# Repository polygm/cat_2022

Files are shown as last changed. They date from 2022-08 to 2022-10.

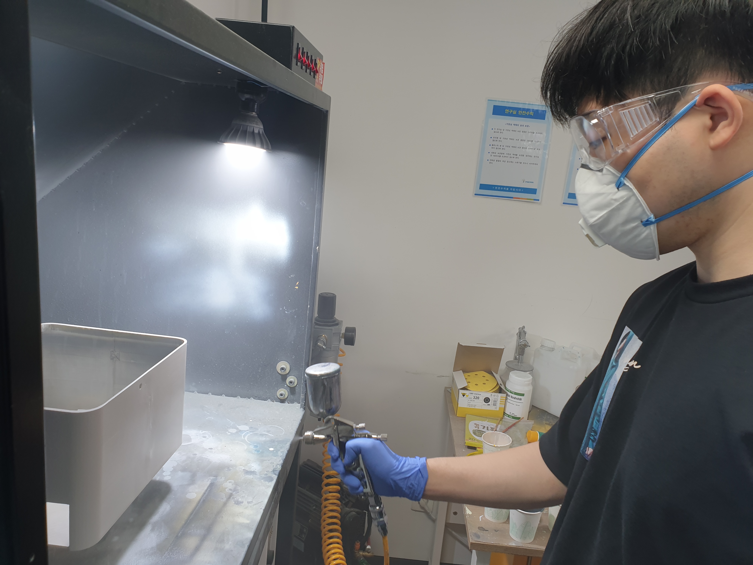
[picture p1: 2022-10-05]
images/KakaoTalk_20221005_131710617_05.jpg

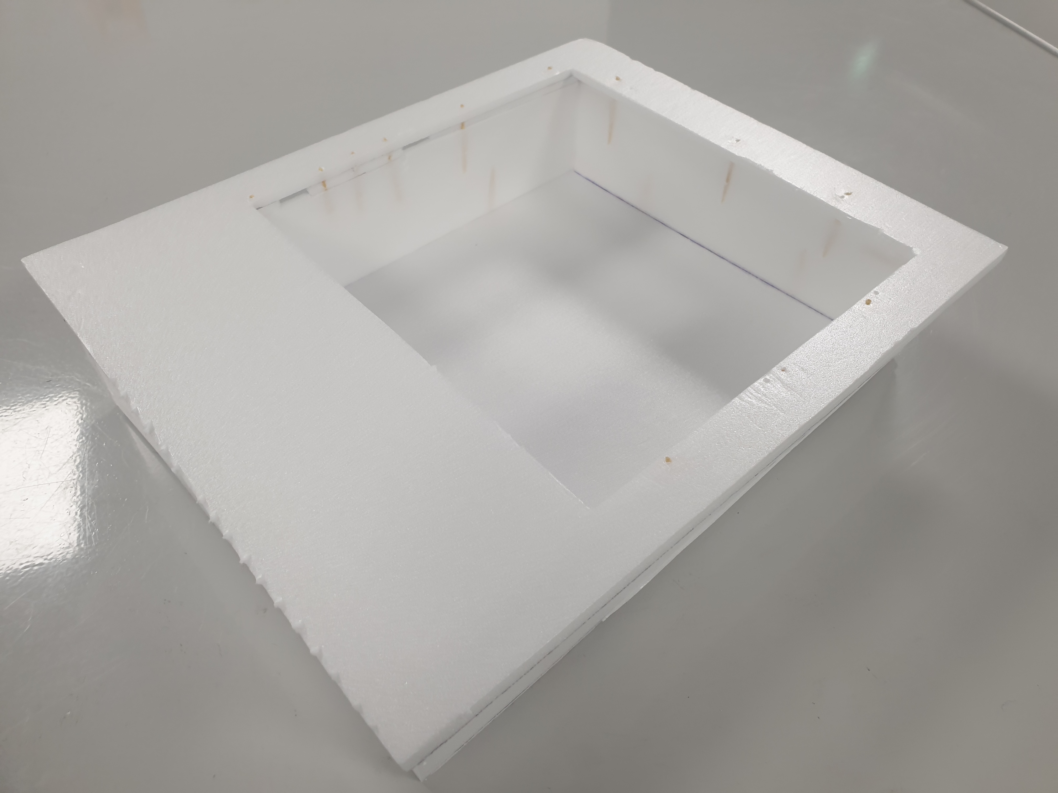
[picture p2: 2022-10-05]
images/KakaoTalk_20220705_105104796_07.jpg

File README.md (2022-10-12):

# CWCT 반려묘 자동배변처리기 프로젝트 github 입니다.

## *benchmarking*
### CWCT 반려묘 자동배변처리기의 구조를 벤치마킹한 제품의 작동 동영상(PLUTO 사의 PLUTO SQUARE)

## *code*
### CWCT 반려묘 자동배변처리기의 주요 기능의 작동을 위해 arduino에 적용시킨 코드

## *doc*
### CWCT 반려묘 자동배변처리기에 관해 작성한 발표 ppt, 공모전 서류 등\

## *images*
### CWCT 반려묘 자동배변처리기를 제작하기 위한 과정을 찍은 사진

## *modeling*
### CWCT 반려묘 자동배변처리기의 주요 prt파일 및 모델링 캡처 사진

## *product*
### CWCT 반려묘 자동배변처리기 완성품 및 주요 요소 사진

## *research*
### CWCT 반려묘 자동배변처리기 프로젝트를 진행하기 위해 조사했던 자료

## 프로젝트 과정 중 탈도 많았고 많이 부족한 프로젝트이지만 향후 여러분의 계획에 도움이 되길 바랍니다.

# 고양이배면 프로젝트
https://kopogm3d.github.io/cat

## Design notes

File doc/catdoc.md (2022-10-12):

# CWCT 반려묘 자동배변처리기 문서 항목입니다.
## 한이음 ICT 관련 문서를 주로 하여 1년 동안의 결과물들을 모아두었습니다.
## 부족한 자료들이지만 향후 여러분의 수학에 도움이 되길 바랍니다.

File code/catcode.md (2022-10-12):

# 두개의 명령어로 왼쪽 오른쪽의 모터이동

A와 B의 입력만으로 동작하게끔 설정

몹시 쉬운 작동방식 구현도 쉽지만 오류도 많다 기본형으로만 참조하세요

---

**init**

아두이노 핀들에 대한 설정

**setup**

핀모드의 아웃풋 인풋 설정

**loop**

블루투스를 통해 입력을 받는 설정과 블루투스의 사용가능을 체크

이후 while을 통해 a와 b입력중 하나를 받는다

입력을 받는다면 while로 모터가 동작하고, 모터의 동작중 포토센서의 입력을 받으면 즉시 정지한다

---

**DCMotor**

구버전, 사용 X

**DCMotor2**

적용된 버전. 위에 내용과 실제 사용된 코드

**Gdk101_____**

로드셀 무게센서 작동을 위한 라이브러리 파일

**StepMotor_Smell**

냄새센서 모듈을 위한 코드

**로드셀 무게센서/weight**

무게센서 작동을 위한 코드

---

수업시간에 듣는거만으로 아주 쉽게 구현가능하고 파악가능합니다

일단 동작하는데에만 의의를 둔거니 다른 동작방식으로 더 좋은 구동 시키길 바랍니다.

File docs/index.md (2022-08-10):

# 프로젝트

## 일정관리

[일정관리](https://docs.google.com/spreadsheets/d/1NQHpdlngy_0xi11DPNy_VgI6_tUYpx1lmcYro-x7uXI/edit?usp=sharing)cd ..
[공유문서](https://drive.google.com/drive/folders/1UJIq0f-sPQG-WJRHgnFJKL07OBTrz0p9?usp=sharing)

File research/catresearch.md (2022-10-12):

# CWCT 반려묘 배변처리기 프로젝트를 진행하며 조사했거나 만들었던 자료들 입니다.
## 한이음 ICT와 같은 작품공모전 성격의 프로젝트를 위한 자료로 반려묘에 관한 여러가지 요소의 변화, 시장조사와 같은 대략적인 흐름과 프로젝트 작품 산출에 필요한 기계, 기구적인 요소 등을 조사하여 모아뒀습니다.
## 부족한 자료들이지만 여러분의 향후 수학에 도움이 되길 바랍니다.

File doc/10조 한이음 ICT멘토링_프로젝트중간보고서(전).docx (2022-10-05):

[붙임2] 한이음 ICT멘토링 프로젝트 중간보고서 서식

한이음 ICT멘토링 프로젝트 중간보고서

프로젝트 정보
프로젝트명 | IOT와 ##을 활용한 반려묘 스마트 화장실
프로젝트 소개 | 현재 반려동물인구가 천만이 넘었지만 그와 반대로 반려동물용품은 보급화가 어려울 정도의 가격대를 형성하는 경우가 많다. 그중 대표적인 것이 반려묘 자동화장실이다. 현재 시중에 있는 수십, 수백만원대의 자동화장실에는 사용빈도가 낮은 부가기능들이 많이 적용되어 있고 이로 인해 가격대가 높아진다고 볼 수 있다. 우리는 이 프로젝트를 통해 핵심기능만을 지닌, 상대적으로 저렴한 반려묘 자동화장실을 소개해보고자 한다.

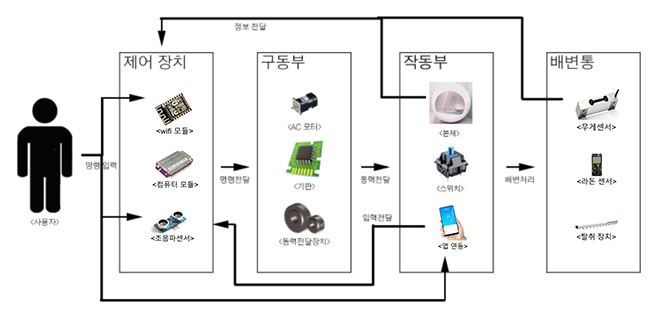
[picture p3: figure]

구성도
개발배경 및 필요성 | 1인 가구의 증대로 현대인들은 외로움을 겪고 있다 이에 따라 반려동물에 대한 수요는 점차 증가하고 있으며 그중 고양이와 개가 가장 친숙하면서 큰 시장이라고 볼 수 있다. 그중 실내에서 더 키우기 적합한 고양이에 포커스를 두고 애묘인들이 가장 힘들어하는 것이 화장실 관리라는 것을 보고 해당 제품을 기획하게 되었다
특・장점 | 기존 타제품의 다양한 기능 중 핵심기능만을 적용하여 저렴한 가격형성이 가능해진다.
주요 기능 | 배변 처리 : 제품의 주요 기능으로, 모래 속에 있는 배변을 자동으로 걸러서 하부 배변 봉투로 분리해주는 기능이다. 모래 평탄화 : 배변 처리 이후 배변용 모래를 평탄화 한다. 고양이 무게 확인 : 반려묘와 변의 무게를 확인한다. 탈취 : 반려묘의 변 냄새가 외부로 새어 나가는 것을 방지한다. IOT : 제품의 원격제어가 가능하다. 라돈 측정 : 배변용 모래의 라돈 수치를 확인한다.
기대효과 및 활용분야

I. 프로젝트 개요

1. 프로젝트 소개

ㅇ 증가한 1인가구에 따라 반려동물에 대한 수요와 시장이 증가하고 있다.

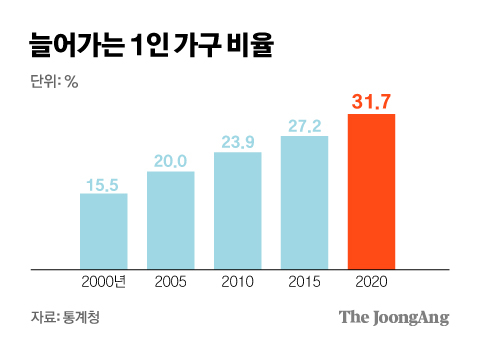
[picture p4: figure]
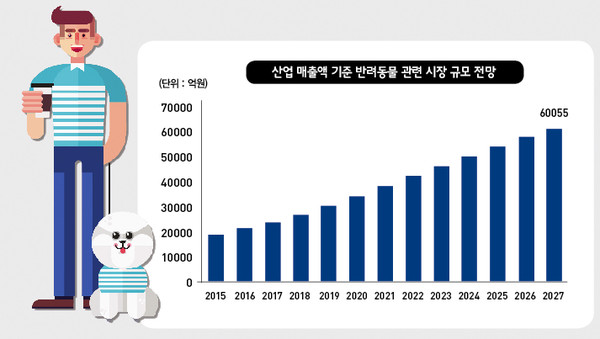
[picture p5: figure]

1인가구 증가비율 반려동물 시장규모 전망

ㅇ 반려동물을 키우는 데에, 배설물, 털 등의 위생관리 부분이 1순위로 꼽힘

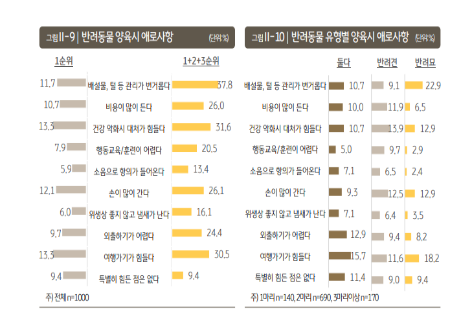
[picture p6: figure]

반려동물 양육 시의 애로사항

ㅇ 도시화 되는 현대사회에 맞춰 1인 가구가 실내에서 더 키우기 적합한 고양이를 선정, 제품으로는 향후 이용 희망율이 가장 높은 자동 화장실을 선정하였다.

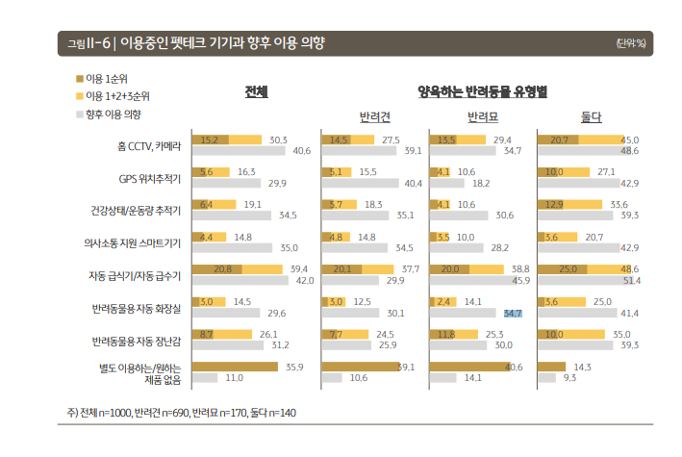
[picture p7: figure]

펫테크 기기와 이용 의향

2. 추진배경 및 필요성

ㅇ 고양이의 청결성과 현대인의 생활습관에 의한 필요

- 고양이는 화장실이 더러우면 다른 곳에 배변을 하는 습성이 있다.

- 바쁜 현대인이 계속해서 관리해주기 어려우므로 자동화 화장실이 관리해 주는데 도움이 된다.

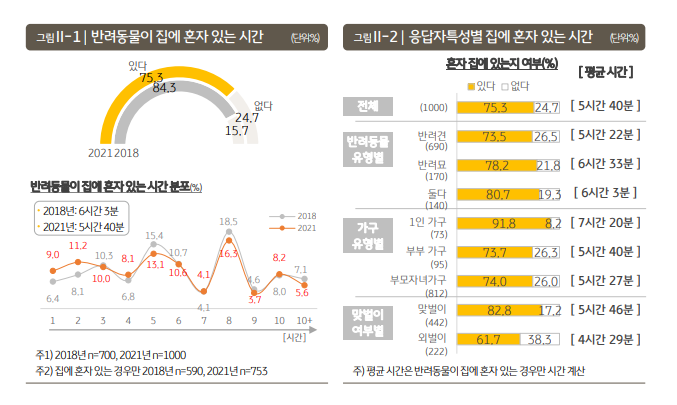
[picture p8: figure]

- 고양이가 실제로 앉는 모래쪽이 배변과 분리되어 청결성을 유지하여 고양이가 다른곳에 배변을 놓는 것을 방지한다.

ㅇ 고양이의 건강관리

- 소개에서 나왔던 것처럼 가장 부담이 되는 건 동물병원비이고, 반려동물의 건강관리는 매우 중요하다

- 배변통에 따로 모여 형태, 냄새, 색깔을 보기 편하고, 횟수를 세므로 간접적으로 건강 상태를 확인하기 쉽다.

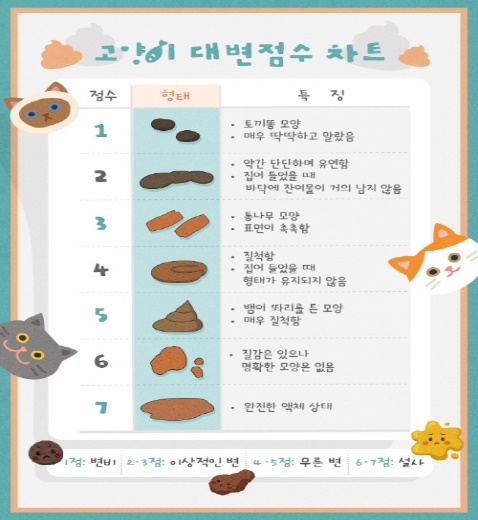
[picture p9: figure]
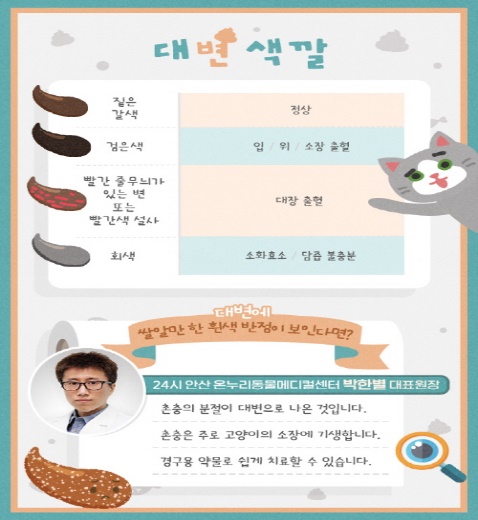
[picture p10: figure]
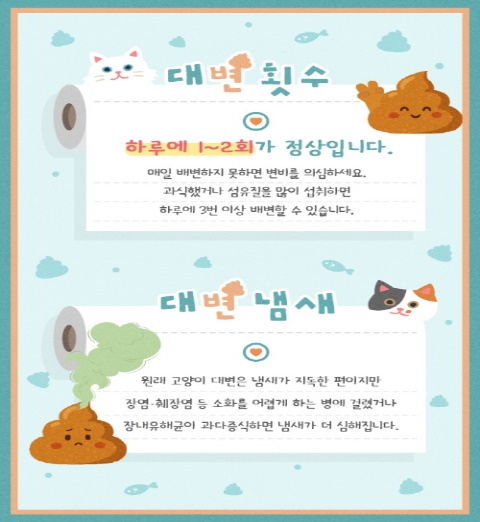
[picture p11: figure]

고양이의 대변과 건강상태

- 위의 정보를 통해 되려 건강관리에 들어가는 비용을 절약할 수 있다.

3. 국내・외 기술 현황

ㅇ

ㅇ

ㅇ

4. 개발목표 및 내용

ㅇ 최종 개발목표

ㅇ 주요 개발내용(기능중심)

ㅇ 기존 기술 활용여부 및 차별성

II. 프로젝트 내용

1. 구성도

ㅇ

- 제어장치

명칭 | 기능 | 설명
Wifi 모듈 | 네트워크를 통해 사용자의 입력, 출력을 담당 | 네트워크를 통해 사용자에게 입력을 받고 컴퓨터 모듈로 명령을 전달함 컴퓨터 모듈에서 받은 정보를 네트워크를 통해 다시 사용자에게 전달함
컴퓨터모듈 | 정보 취합 후 출력 | 해당 기기의 본체에 해당 모든 정보를 받고 취합하여 각 모듈로 전달 모든 명령과 정보 처리를 담당
초음파센서 | 고양이의 출입 감지 | 고양이의 출입 감지 시 제품 작동 시작 및 종료

- 구동부

명칭 | 기능 | 설명
AC 모터 | 전원을 받고 동력을 생성함 | 전기를 통해 동력을 생성하는 역할 컴퓨터 모듈에서 받은 명령을 단순수행
기판 | 제어창에서 명령을 받고 구동부를 작동시킴 | 제어장치를 포함, 명령을 전달하는 기판 모터를 돌리게 하고 동력전달장치를 가동시킴 또한 정지를 관여함
동력전달장치 | 모터에서 발생된 운동에너지를 작동부로 전달함 | 모터에서 받은 동력을 작동부로 전달시킴

- 작동부

명칭 | 기능 | 설명
동작 센서 | 고양이의 동작을 감지 | 고양이의 동작을 감지해서 컴퓨터 모듈로 전달 해당 입력을 감지해 정지, 작동을 판단
본체 | 동력을 받아 회전 | 동력전달장치로부터 동력을 전달 받아 회전함으로써 내부의 배변을 걸러냄
스위치 | 사용자의 직접 입력을 받음 | 외부에 돌출된 기계식 버튼의 스위치 사용자의 입력을 직접 받아 컴퓨터 모듈로 전달

- 배변통

명칭 | 기능 | 설명
무게센서 | 무게를 감지 | 고양이의 무게 감지 시 작동 시작 종료
배변통 본체 | 배변을 담는 통 | 단순 배변을 담는 통 봉투를 끼울 수 있게 용이하게 제작됨
탈취 필터 | 배변의 냄새 억제 | 배변의 냄새를 억제하는 필터 배변통안쪽 장착하기 쉽게 설계
라돈센서 | 라돈수치측정 | 모래에서 발생하는 라돈수치를 측정함

2. 주요기능

ㅇ 전체 기능 목록

구분 | 기능 | 설명 | 현재진척도(%)
S/W | IoT | 원격으로 제품에 대한 접근, 조작을 사용자에게 제공
H/W | 고양이 감지
| 배변처리

ㅇ S/W 주요 기능

기능 | 설명

ㅇ H/W 주요 기능

기능/부품 | 설명

3. 적용기술

ㅇ

ㅇ

ㅇ

4. 예상 결과물

예상 결과물 이미지 | 설명

III. 프로젝트 수행내용

1. 프로젝트 수행일정

프로젝트 기간 (한이음 사이트 기준) | | 2020.04.12. ~ 2020.10.28.
구분 | 추진내용 | 프로젝트 기간
| | 1월 | 2월 | 3월 | 4월 | 5월 | 6월 | 7월 | 8월 | 9월 | 10월 | 11월 | 12월
계획 | 조원 구성 및 역할분담, 일정 협의 및 일정표 작성, 제품 사전조사, 제품 사전조사, 수행계획서 작성 | | | ㅇ | ㅇ
분석 | 구현여부확인, 제품 필수기능 설정, 제품디자인 외형 설정, 제품의 구동방식 확인, 시제품 비교군 탐색, 수정보안점 확인 | | | | ㅇ | ㅇ
설계 | 3D도면 제작 및 검수 | | | | | ㅇ | ㅇ
| 2D도면 제작 및 검수 | | | | | ㅇ | ㅇ
개발 | 3D프린터를 활용한 시안 제작 | | | | | | ㅇ | ㅇ
| 제품 검증 및 시제품 재료 구매 | | | | | | | ㅇ
| 시제품 제작 | | | | | | | ㅇ
테스트 | 시제품 구동확인 및 오류수정 | | | | | | | ㅇ
종료 | 프로젝트 최종보고 및 종료 | | | | | | | ㅇ

2. 프로젝트 수행 과정에서의 문제점 및 애로사항

ㅇ

ㅇ

ㅇ

VI. 기대효과 및 개선사항

1. 기대효과

ㅇ

ㅇ

ㅇ

2. 개선사항

ㅇ

ㅇ

ㅇ

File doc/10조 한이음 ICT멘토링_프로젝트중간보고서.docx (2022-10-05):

[붙임2] 한이음 ICT멘토링 프로젝트 중간보고서 서식

한이음 ICT멘토링 프로젝트 중간보고서

프로젝트 정보
프로젝트명 | IOT를 활용한 반려묘 스마트 화장실
프로젝트 소개 | 현재 반려동물인구가 천만이 넘었지만 그와 반대로 반려동물용품은 보급화가 어려울 정도의 가격대를 형성하는 경우가 많다. 그중 대표적인 것이 반려묘 자동화장실이다. 현재 시중에 있는 수십, 수백만원대의 자동화장실에는 사용빈도가 낮은 부가기능들이 많이 적용되어 있고 이로 인해 가격대가 높아진다고 볼 수 있다. 우리는 이 프로젝트를 통해 핵심기능만을 지닌, 기존 제품 대비 상대적으로 보급에 유리한 반려묘 자동화장실을 소개해보고자 한다.

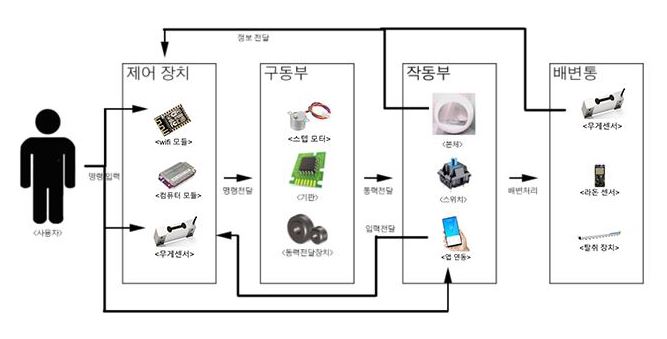
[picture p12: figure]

구성도
개발배경 및 필요성 | 1인 가구의 증대로 현대인들은 외로움을 겪고 있다 이에 따라 반려동물에 대한 수요는 점차 증가하고 있으며 그중 고양이와 개가 가장 친숙하면서 큰 시장이라고 볼 수 있다. 그중 실내에서 더 키우기 적합한 고양이에 포커스를 두고 애묘인들이 가장 힘들어하는 것이 화장실 관리라는 것을 보고 해당 제품을 기획하게 되었다
특・장점 | 기존 타제품의 다양한 기능 중 핵심기능만을 적용하여 저렴한 가격형성이 가능해진다.
주요 기능 | ▶ 배변 처리 : 제품의 주요 기능으로, 모래 속에 있는 배변을 자동으로 걸러서 하부 배변 봉투로 분리해주는 기능이다. ▶ 모래 평탄화 : 배변 처리 이후 배변용 모래를 평탄화 한다. ▶ 고양이 무게 확인 : 반려묘와 변의 무게를 확인한다. ▶ IOT : 제품의 원격제어가 가능하다. ▶ 라돈 측정 : 배변용 모래의 라돈 수치를 확인한다. ▶ 탈취 : 반려묘의 변 냄새가 외부로 새어 나가는 것을 방지한다.
기대효과 및 활용분야 | 자동제어와 원격제어를 통해 외출 등의 이유로 보호자가 직접 제품을 관리할 수 없을 때 화장실 관리를 가능하게 한다. 핵심 기능만을 적용하여 원가 절감이 가능해 자동화장실의 보급화에 유리하다.

I. 프로젝트 개요

1. 프로젝트 소개

ㅇ 반려동물 시장의 성장은 1인 가구의 증가, 소득수준 향상, 저출산, 고령화 등 다양한 사회, 환경적 요인이 복합적으로 더해져 생긴 현상이다. 국내의 반려동물 시장은 매년 15%씩 성장하고 있고 미국, 영국, 일본 등의 선진국들의 예로 볼 때 국내 반려동물 시장의 관심은 더욱 커질 것으로 보인다.

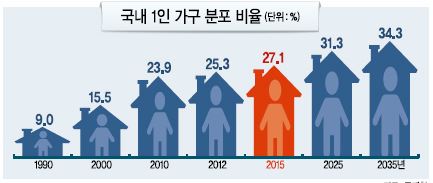
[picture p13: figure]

<표 1> 1인가구 증가비율(통계청) <표 2> 반려동물 시장규모 전망(농수축산신문 안희경,송형근 기자)

ㅇ 우리나라의 경우 특히 2006년 이후 반려동물로 급증하고 있는 고양이 관련 산업이 강한 성장세로 반려동물 상업 매출 증가에 큰 영향을 미치고 있다. 2012년 기준으로 국내에서 개나 고양이를 반려동물로 기르는 비율은 17.9%로 약 359만 가구, 인구수로 환산하면 천만 명에 달하며, 동물의 수로는 556만 마리로 추산되며, 그중 고양이는 116만 마리이다. 고양이의 양육 비중은 2006년 47만 7000마리에서 2012년 116만 마리로 240% 급증했는데, 이는 사회적 요인과 고양이에 대한 의식구조의 변화에 의한 것으로 볼 수 있다. 결혼과 출산율 감소, 고령화 등의 이유로 1인 가구가 늘고 그로 인한 외로움을 반려동물을 통해 해소하려는 경향이 높아지고 있으며, 고양이에 대한 부정적인 인식 개선, 고양이의 적은 채취, 소음, 적응력과 독립적인 성향이 현재 반려인들의 라이프 스타일에 잘 적응할 수 있는 점이 고양이 사육 개체수의 증가에 큰 영향을 주고 있다.


<표 3> 반려동물 양육 시의 애로사항(KB금융그룹 2021 한국 반려동물 보고서’)

2. 추진배경 및 필요성

ㅇ 반려인들이 국내 고양이 사육 가구의 수가 급증하고 있음에도 불구하고 고양이 관련 산업 관련 제품에 대한 국내 연구는 찾아보기 힘들며, 국산 브랜드의 인지도는 현저히 낮은 상황이다. 현재 시중에 나와있는 고양이 자동화장실의 가격대는 수십만원대에서 수백만원을 호가하는 제품까지 있으며, 이는 고양이 반려인들에게 큰 부담으로 다가온다.


<표 4, 5> 반려동물이 혼자 있는 시간(KB금융그룹 2021 한국 반려동물 보고서’)

ㅇ 반려인들이 반려동물을 키우면서 생기는 문제점 1순위가 위생과 비용적인 문제점인데, 1인 가구가 증가하는 추세인 현대에 반려동물이 홀로 있게 되는 시간이 길어지는 것은 불가피하며, 이는 고양이 화장실에 방치되어 있는 변에 의한 세균증식으로 이어진다. 이는 집 안의 악취와 고양이의 건강에 직접적으로 영향을 주는 문제이며 반려인들이 뽑는 문제점 1순위와 크게 연관된다. 그렇기 때문에 자동화장실의 필요성이 부각된다.


<표 6> 펫테크 기기와 이용 의향(KB금융그룹 2021 한국 반려동물 보고서’)


<표 7> 고양이의 대변과 건강상태(헬스경향 김보람 기자)

3. 국내・외 기술 현황

ㅇ 고양이의 습성상 배변을 할 때 개방된 공간을 선호하지만 냄새 억제, 사막화 방지 등을 이유로 현재 대부분의 자동화장실은 폐쇄형으로 디자인된다.

ㅇ 현재 주류인 폐쇄형이면서 구형 디자인이 주를 이루는 고양이 화장실은 구조적, 경제적인 이유로 인해 고양이가 선호하는 공간 크기인 고양이 체장의 1.5배를 만족시키기 힘들다.

ㅇ 어플과의 연동으로 인해 실시간 모니터링, 응급 시 자동연결 기능 등 자동화장실의 편의성을 높이는 부가기능들이 많이 적용되는 추세이지만 반대로 자동화장실을 고가로 만드는 원인이기도 하다.

4. 개발목표 및 내용

ㅇ 최종 개발목표

- 필수 핵심기능과 최소한의 부가기능만 적용해 고양이 자동화장실의 경제성 확보 및 보편화 증대

ㅇ 주요 개발내용(기능중심)

- 모터와 기어의 동력전달에 의한 회전운동을 이용한 배변처리와 모래 평탄화

- Wifi 모듈과 컴퓨터 모듈의 연결을 통한 앱 연동으로 사용자에게 핸드폰 등을 통한 제품의 원격제어 및 센서에서 산출된 정보의 가시화 제공

- 무게센서, 라돈 센서의 측정을 컴퓨터 모듈에 전달하고 그것을 신호로 하여 제품의 자동제어 수행

ㅇ 기존 기술 활용여부 및 차별성

| 기존제품 | 반려묘 스마트 화장실

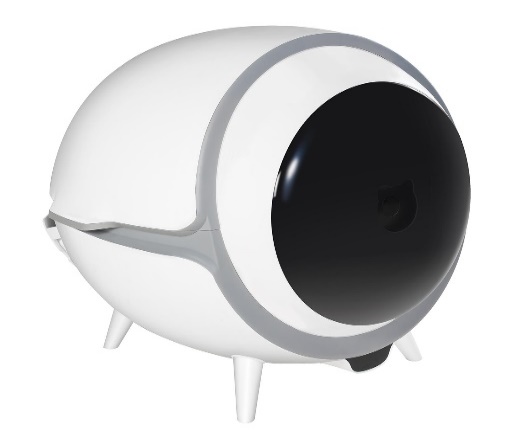
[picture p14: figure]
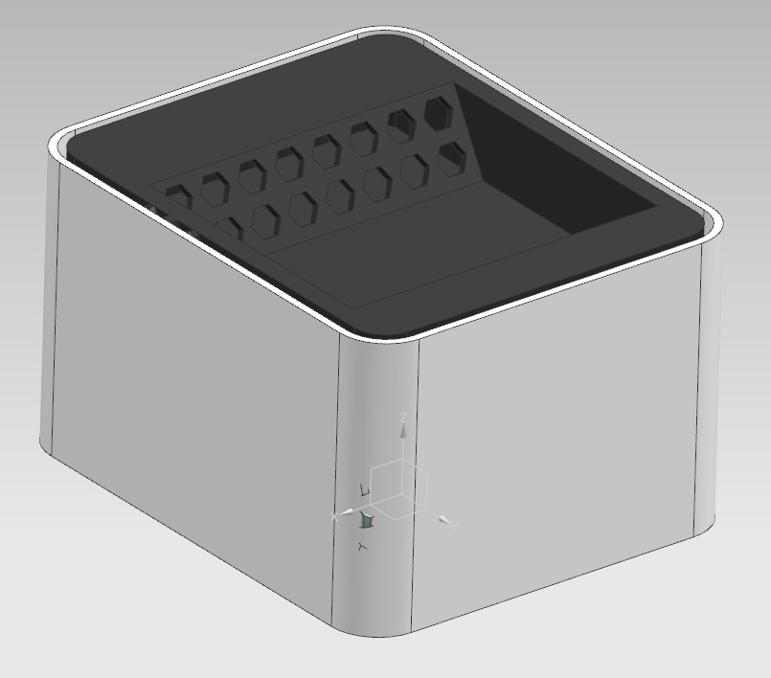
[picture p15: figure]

외형 | (https://catpre.com/product/38384)
특징 | 폐쇄형 제품 회전 | 개방형 상단면 일부 회전
기술 | 고양이 배변 자동처리 무선 연동 UV 살균 체중 측정 고양이 출입 시 일시정지 LED 표기 | 고양이 배변 자동처리 무선연동 라돈 측정 체중 측정 고양이 출입 시 일시정지 LED 표기
가격 | 고가 | 저가

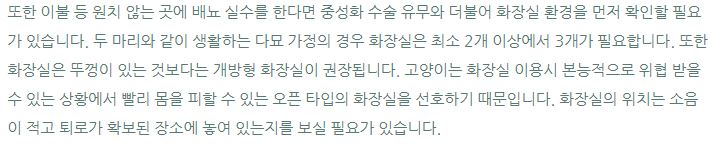
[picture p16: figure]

(참고 자료 - https://blog.naver.com/animalandhuman/221152328930, 나응식 수의사)

- 밀폐형의 구형 구조를 지닌 기존 대다수의 제품은 디자인적 측면과 악취 예방에 좀 더 효과적이지만 개방형 구조를 선호하는 고양이에게 악영향을 줄 수 있다. 또한 복잡한 구형 구조로 인해 설계 및 제작의 난이도가 올라가 제품의 가격을 상승시키는 요인이 된다.

그에 비해 우리 제품은 개방된 판형 구조로 고양이가 받는 스트레스를 줄일 수 있고, 단순한 판형 디자인과 단순회전운동을 통한 배변처리방식으로 작동해 제작의 효율성이 높아져 제품의 가격을 절감시킬 수 있을 것이라 예상한다.

(참고 자료 – https://www.quora.com/Do-cats-prefer-open-or-closed-litter-boxes , https://www.litter-robot.com/blog/why-do-cats-use-litter-boxes/)

II. 프로젝트 내용

1. 구성도

- 제어장치

명칭 | 기능 | 설명
Wifi 모듈 | 네트워크를 통해 사용자의 입력, 출력을 담당 | 네트워크를 통해 사용자에게 입력을 받고 컴퓨터 모듈로 명령을 전달함 컴퓨터 모듈에서 받은 정보를 네트워크를 통해 다시 사용자에게 전달함
컴퓨터 모듈 | 정보 취합 후 출력 | 해당 기기의 본체에 해당 모든 정보를 받고 취합하여 각 모듈로 전달 모든 명령과 정보 처리를 담당
무게센서 | 무게 측정으로 고양이의 출입 감지 | 고양이의 출입 감지 시 제품 작동 시작 및 종료

- 구동부

명칭 | 기능 | 설명
스텝 모터 | 전원을 받고 동력을 생성함 | 전기를 통해 동력을 생성하는 역할 컴퓨터 모듈에서 받은 명령을 단순수행
기판 | 제어창에서 명령을 받고 구동부를 작동시킴 | 제어장치를 포함, 명령을 전달하는 기판 모터를 돌리게 하고 동력전달장치를 가동시킴 또한 정지를 관여함
동력전달장치 | 모터에서 발생된 운동에너지를 작동부로 전달함 | 모터에서 받은 동력을 작동부로 전달시킴

- 작동부

명칭 | 기능 | 설명
본체 | 동력을 받아 회전 | 동력 전달 장치로부터 동력을 전달받아 회전함으로써 내부의 배변을 걸러냄
스위치 | 사용자의 직접 입력을 받음 | 외부에 돌출된 기계식 버튼의 스위치 사용자의 입력을 직접 받아 컴퓨터 모듈로 전달
앱 연동 | 라돈 수치측정 | 앱 연동을 통해 핸드폰 등의 기기로 제품의 배변처리 등을 제품과 떨어져 있을 때 원격으로 제어하게 해주며, 산출된 무게와 라돈 수치 등을 가시화

- 배변통

명칭 | 기능 | 설명
무게센서 | 무게를 측정 | 고양이 및 변의 무게를 감지하여 화장실의 내부 상황 파악 및 간단한 검진 가능
탈취 필터 | 배변의 악취 억제 | 배변의 악취를 억제하는 필터
라돈 센서 | 라돈 수치측정 | 모래에서 발생하는 라돈 수치를 측정함

2. 주요기능

ㅇ 전체 기능 목록

구분 | 기능 | 설명 | 현재진척도(%)
S/W | IoT | 원격으로 제품에 대한 접근, 조작을 사용자에게 제공
H/W | 고양이 출입 감지 | 고양이의 출입을 감지하여 제품의 작동 제어
| 배변처리 | 판이 회전하면서 모래 속에 있는 배변을 분리하고 배변통으로 배출함
| 모래 평탄화 | 판 안의 배변용 모래를 판의 회전을 통해 평탄화
| 라돈 측정 | 배변용 모래에서 검출되는 라돈의 수치 측정
| 무게 측정 | 고양이와 변의 무게를 측정
| 탈취 필터 | 배변의 악취 억제

ㅇ S/W 주요 기능

기능 | 설명
IoT | Wifi모듈, 컴퓨터 모듈과의 연결로 핸드폰 등의 기기를 통한 제품의 자동제어, 원격제어 부여. 무게와 라돈 수치 등 산출된 정보를 가시화

ㅇ H/W 주요 기능

기능/부품 | 설명
컴퓨터 모듈 | 제품의 구동부, 센서와 결합하여 고양이의 출입을 통한 제품의 작동 자동제어
모터 및 동력전달장치 | 모터의 동력을 통한 제품의 다양한 각도의 회전운동을 통해 배변처리 및 모래 평탄화 진행
무게센서 | 무게측정을 통해 고양이의 출입을 감지 고양이와 변의 잔류를 무게 측정을 통해 확인할 수 있으며 그 신호에 의해 반복 작동 필요 판단. 고양이와 변의 무게 측정을 통한 간단한 검진 가능
라돈 센서 | 배변용 모래의 라돈 수치를 측정하여 모래의 교체 필요성 확인 및 사고 예방
탈취 필터 | 배변의 악취를 억제하여 외부로의 유출 방지

3. 적용기술

ㅇ 모터와 기어의 동력전달에 의한 회전운동을 이용한 배변처리와 모래 평탄화

ㅇ 무게센서, 라돈 센서의 측정을 컴퓨터 모듈에 전달하고 그것을 신호로 하여 제품의 자동제어 수행

ㅇ Wifi 모듈과 컴퓨터 모듈의 연결을 통한 앱 연동으로 사용자에게 핸드폰 등을 통한 제품의 원격제어 및 센서에서 산출된 정보의 가시화 제공

4. 예상 결과물

예상 결과물 이미지 | 설명
별첨1. | 제품의 완성품으로 구동 시 상단의 판의 회전으로 첫 회전 시 90 ° 각도로 회전하여 변을 하단의 배변통으로 거르고 모래를 홈 뒤편의 공간으로 분리시킨 뒤 다음 회전 시 90 °미만의 각도로 회전하여 모래를 다시 판으로 가져온다. 마지막 회전 시 모래를 평탄화 한다. (참고 동영상 https://www.youtube.com/watch?v=ReGhS7GVbm0)
별첨2. | 제품의 구동부로 위 완성품의 회전운동을 담당하는 부분이다. 모터와 수직으로 배치된 기어들이 힘을 전달하고 마지막으로 회전판 측면의 기어 이빨이 힘을 받아 판을 회전시킨다. 기어의 규격 및 개수는 완성품의 정확한 규격과 모터의 출력 등을 기반으로 하여 결정할 예정이다.

III. 프로젝트 수행내용

1. 프로젝트 수행일정

프로젝트 기간 (한이음 사이트 기준) | | 2020.04.12. ~ 2020.10.28.
구분 | 추진내용 | 프로젝트 기간
| | 1월 | 2월 | 3월 | 4월 | 5월 | 6월 | 7월 | 8월 | 9월 | 10월 | 11월 | 12월
계획 | 조원 구성 및 역할분담, 일정 협의 및 일정표 작성, 제품 사전조사, 제품 사전조사, 수행계획서 작성 | | | ㅇ | ㅇ
분석 | 구현여부확인, 제품 필수기능 설정, 제품디자인 외형 설정, 제품의 구동방식 확인, 시제품 비교군 탐색, 수정보안점 확인 | | | | ㅇ | ㅇ
설계 | 3D도면 제작 및 검수 | | | | | ㅇ | ㅇ
| 2D도면 제작 및 검수 | | | | | ㅇ | ㅇ
개발 | 3D프린터를 활용한 시안 제작 | | | | | | ㅇ | ㅇ
| 제품 검증 및 시제품 재료 구매 | | | | | | | ㅇ | ㅇ
| 시제품 제작 | | | | | | | ㅇ | ㅇ | ㅇ
테스트 | 시제품 구동확인 및 오류수정 | | | | | | | | | ㅇ | ㅇ
종료 | 프로젝트 최종보고 및 종료 | | | | | | | | | | ㅇ | ㅇ

2. 프로젝트 수행 과정에서의 문제점 및 애로사항

ㅇ 제품의 구조와 구동에 필요한 지식 부족

ㅇ IoT기술을 접목시키기 위한 아두이노 코딩의 이해 부족

ㅇ 신청 자재의 품절 및 배송 지연으로 인한 일정 지연

VI. 기대효과 및 개선사항

- 기대효과

ㅇ

<표 8> 반려동물 월평균 양육비용(농림축산식품부)

<참고 기사-연합뉴스>

반려인들의 반려동물 양육 시 애로사항 1, 2위가 위생 관리, 지출 문제로 꼽히고 있는데 우리 제품은 언제든지 배변처리, 소결 등이 가능하기 때문에 위생 관리에 유리하다. 또한 반려묘 및 변의 무게 측정, 배변용 모래의 라돈 수치 측정을 통해 간단한 검진을 할 수 있어 반려묘의 병원비 지출도 낮출 수 있다. 이러한 점으로 가정과 요즘 많아지고 있는 펫 카페 등 다중시설에서의 구비가 손쉬워져 결과적으로 자동화장실 보급에 탄력을 줄 수 있을 것이라 생각한다.

2. 개선사항

ㅇ 초안의 음성인식기술 적용을 원가절감과 제작의 용이성 등을 위해 배제시킴.

ㅇ 기존의 초음파센서를 통한 출입감지 방식을 제작의 용이성 등을 위해 배제시킴

별첨.

II. 프로젝트 내용. 4. 예상 결과물

별첨1.

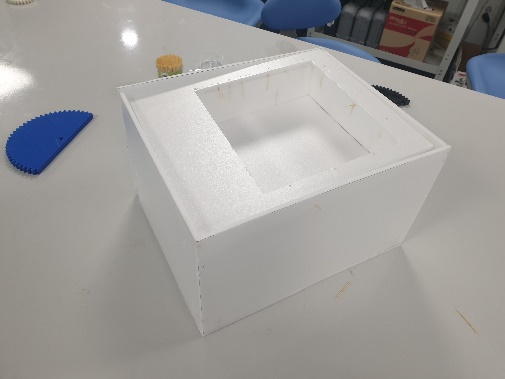
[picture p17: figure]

완성품

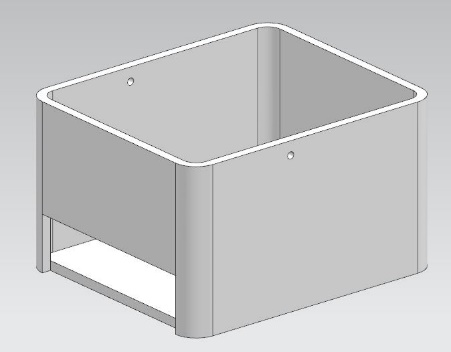
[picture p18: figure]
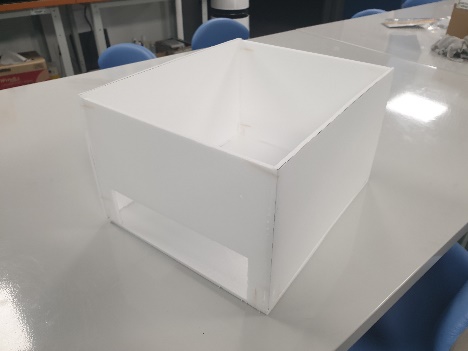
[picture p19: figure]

본체

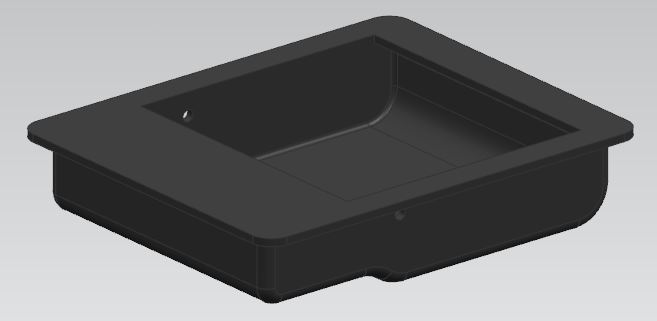
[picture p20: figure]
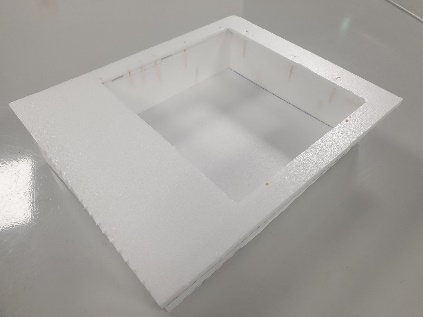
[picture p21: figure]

모래통

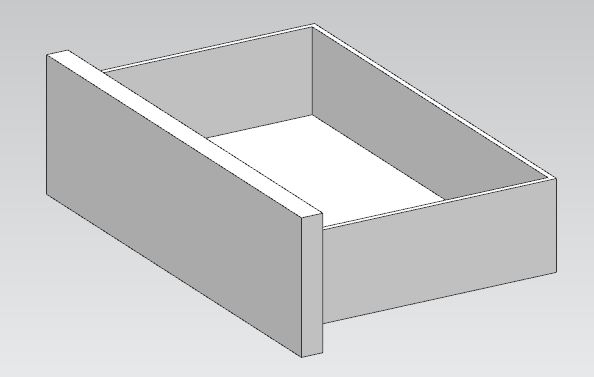
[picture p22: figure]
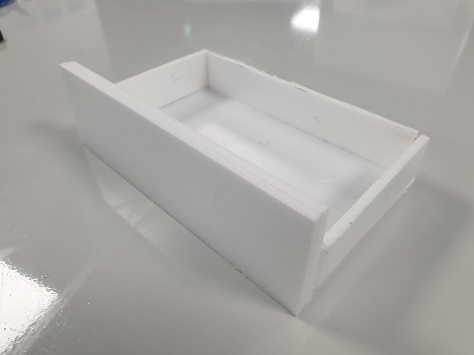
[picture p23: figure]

배변통

별첨2.

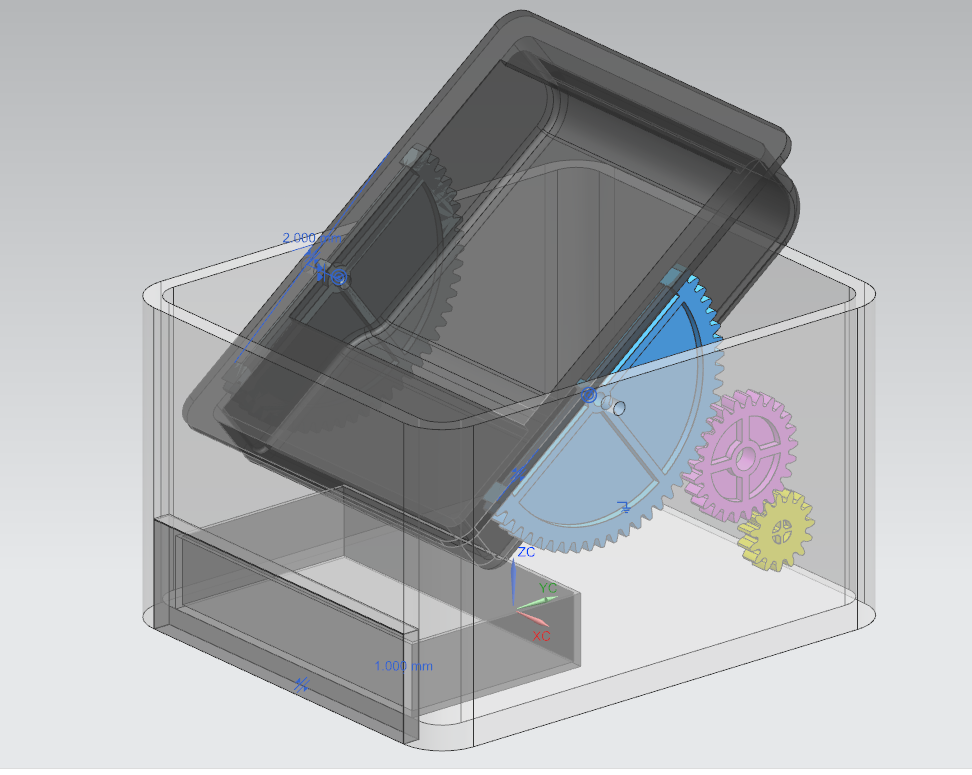
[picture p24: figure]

2

3

1

제품 내부 배치도(1 – 상단기어 2 – 중간기어 3 – 하단기어)

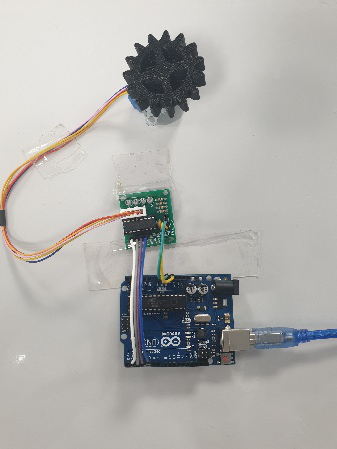
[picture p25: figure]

하단 기어+모터

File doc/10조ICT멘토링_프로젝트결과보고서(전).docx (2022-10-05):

□ 서식4_한이음 ICT멘토링 프로젝트 결과보고서

2020년 한이음 ICT멘토링

프로젝트 결과보고서

프로젝트명 | IOT기술을 활용한 반려묘 스마트 화장실

요 약 본

프로젝트 정보
주제영역 | ■ 생활 □ 업무 □ 공공/교통 □ 금융/핀테크 □ 의료 □ 교육 □ 유통/쇼핑 □ 엔터테인먼트
기술분야 | ■ IoT □ 가상현실 | □모바일 □ 빅데이터 | □ 데스크톱 SW ■ 자동제어기술 | □인공지능 □ 블록체인 | □ 보안 □ 영상처리
달성성과 | ■ 논문게재 및 포스터발표 □ 앱등록 □ 프로그램등록 □ 특허 □ 기술이전 ■ 실용화 □공모전(공모전명 ) □ 기타( )
프로젝트명 | IOT기술을 활용한 반려묘 스마트 화장실
프로젝트 소개 | 바쁜 현대의 반려인들에게 자동화장실은 필수라 해도 과언이 아니나 복잡한 구조와 여러 가지 부가기능으로 인해 그 가격이 매우 비싸 보급률이 낮다. 우리는 이 프로젝트를 통해 핵심기능만을 지닌, 기존 제품 대비 상대적으로 보급에 유리한 반려묘 자동화장실을 소개해보고자 한다.
개발배경 및 필요성 | 1인 가구의 증대로 반려동물에 대한 수요는 점차 증가하고 있으며 그중 실내에서 키우기 적합한 고양이에 포커스를 두고 애묘인들이 가장 힘들어하는 것이 화장실 관리라는 것을 보고 해당 제품을 기획하게 되었다.
프로젝트 주요기능 | ▶ 배변 처리 : 제품의 주요 기능으로, 모래 속에 있는 배변을 자동으로 걸러서 하부 배변 봉투로 분리해주는 기능이다. ▶ 모래 평탄화 : 배변 처리 이후 배변용 모래를 평탄화 한다. ▶ 고양이 무게 확인 : 반려묘와 변의 무게를 확인한다. ▶ IOT : 제품의 원격제어가 가능하다. ▶ 라돈 측정 : 배변용 모래의 라돈 수치를 확인한다. ▶ 탈취 : 반려묘의 변 냄새가 외부로 새어 나가는 것을 방지한다.
작품의 기대효과 및 활용분야 | 자동제어와 원격제어를 통해 외출 등의 이유로 보호자가 직접 제품을 관리할 수 없을 때 화장실 관리를 가능하게 한다. 핵심기능만을 적용하여 원가 절감이 가능해 자동화장실의 보급화에 유리하다.

(본문) 프로젝트 결과보고서

Ⅰ. 프로젝트 개요

가. 프로젝트 소개

1) 반려동물 시장의 성장

-1인 가구의 증가, 소득수준 향상, 저출산, 고령화 등 다양한 사회, 환경적 요인에 의한 현상

- 국내 반려동물 시장의 경우 매해 전년 대비 15%씩 상승


<표 1> 1인가구 증가비율(통계청) <표 2> 반려동물 시장규모 전망(농수축산신문 안희경, 송형근 기자)

2) 고양이 시장의 급성장

- 현대인의 바쁜 일상과 고양이의 적은 채취와 소음, 독립적 성향에 기인함

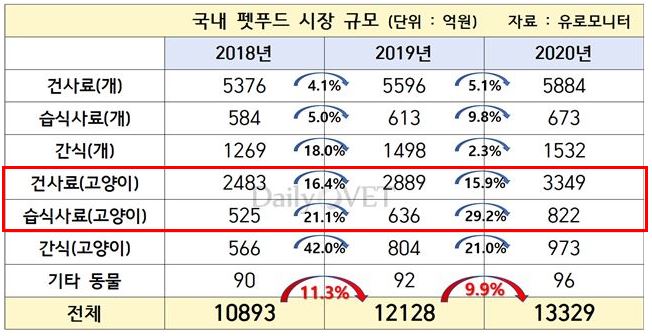
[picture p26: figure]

<표 3> 국내 반려동물 사료 시장 규모(유로모니터)

나. 개발배경 및 필요성


<표 5, 6> 반려동물이 혼자 있는 시간(KB금융그룹 2021 한국 반려동물보고서’)


<표 4> 펫테크 기기와 이용 의향(KB금융그룹 2021 한국 반려동물 보고서’)

1) 장시간 혼자 있는 반려동물 때문에 다수의 반려인들이 자동화장실 사용을 희망함.


<표 7> 반려동물 양육 시의 애로사항(KB금융그룹 2021 한국 반려동물 보고서’)

2) 반려동물 양육 시 발생하는 문제점 1순위는 위생적, 비용적 문제

자동화장실의 필요성 부각


<표 8> 고양이의 대변과 건강상태(헬스경향 김보람 기자)

다. 작품 구성도

ㅇ


- 제어장치

명칭 | 기능 | 설명
Wifi 모듈 | 네트워크를 통해 사용자의 입력, 출력을 담당 | 네트워크를 통해 사용자에게 입력을 받고 컴퓨터 모듈로 명령을 전달함 컴퓨터 모듈에서 받은 정보를 네트워크를 통해 다시 사용자에게 전달함
컴퓨터모듈 | 정보 취합 후 출력 | 해당 기기의 본체에 해당 모든 정보를 받고 취합하여 각 모듈로 전달 모든 명령과 정보 처리를 담당
초음파센서 | 고양이 출입을 감지 | 고양이의 출입 감지 시 제품 작동 시작 및 종료

- 구동부

명칭 | 기능 | 설명
AC 모터 | 전원을 받고 동력을 생성함 | 전기를 통해 동력을 생성하는 역할 컴퓨터 모듈에서 받은 명령을 단순수행
기판 | 제어창에서 명령을 받고 구동부를 작동시킴 | 제어장치를 포함, 명령을 전달하는 기판 모터를 돌리게 하고 동력전달장치를 가동시킴 또한 정지를 관여함
동력전달장치 | 모터에서 발생된 운동에너지를 작동부로 전달함 | 모터에서 받은 동력을 작동부로 전달시킴

- 작동부

명칭 | 기능 | 설명
동작 센서 | 고양이의 동작을 감지 | 고양이의 동작을 감지해서 컴퓨터 모듈로 전달 해당 입력을 감지해 정지, 작동을 판단
본체 | 동력을 받아 회전 | 동력전달장치로부터 동력을 전달 받아 회전함으로써 내부의 배변을 걸러냄
스위치 | 사용자의 직접 입력을 받음 | 외부에 돌출된 기계식 버튼의 스위치 사용자의 입력을 직접 받아 컴퓨터 모듈로 전달

- 배변통

명칭 | 기능 | 설명
무게센서 | 무게를 감지 | 고양이의 무게 감지 시 작동 시작 종료
탈취 장치 | 배변의 냄새 억제 | 배변의 냄새를 억제하는 필터 배변통 안쪽 장착하기 쉽게 설계
라돈 센서 | 라돈 수치측정 | 모래에서 발생하는 라돈 수치를 측정함

라. 작품의 특징 및 장점

ㅇ 기존 제품의 다양한 기능 중 핵심기능만을 제외하여 저렴한 가격대 형성이 가능하다.

Ⅱ. 프로젝트 수행결과

가. 주요기능

구분 | 기능 | 설명
S/W | IoT | 원격으로 제품에 대한 접근, 조작을 사용자에게 제공
H/W | 고양이 감지 | 고양이의 출입을 감지하여 제품의 작동 제어
| 배변처리 | 판이 회전하면서 모래 속에 있는 배변을 분리하고 배변통으로 배출함
| 모래 평탄화 | 판 안의 배변용 모래를 판의 회전을 통해 평탄화
| 센서제어 | 다수의 스위치나 센서로부터 값을 받아들여 LED나 모터와 같은 외부 전자장치들을 통제함으로써 환경과 상호작용이 가능한 물건을 만들어낼 수 있다. 임베디드 시스템 중의 하나로 쉽게 개발할 수 있는 환경을 이용하여, 장치를 제어할 수 있다.

나. 프로젝트 개발환경

구분 | | 항목 | 적용내역
S/W 개발환경 | OS
| 개발환경(IDE)
| 개발도구
| 개발언어
H/W 구성장비 | 디바이스
| 센서 | 초음파센서
| | 무게센서
| | 라돈 센서
| 통신
| 개발언어

다. 장비(기자재/재료) 활용

번호 | 품명 | 작품에서의 주요기능
1 | 갤럭시S5 | -
2 | 라즈베리파이 | -
3 | | -
4 | | -

라. 프로그램 작동 동영상

#URL(유튜브에 올려서 링크 – 프로그램 작동 되는 화면을 동영상으로 작성)

ㅇ

ㅇ

마. 결과물 상세 이미지

(이미지 첨부) | (이미지 첨부) | (이미지 첨부)

바. 달성성과

□ | 논문게재 및 포스터발표 | 게재(발표)자명 | 논문(포스터)명 | 게재(발표)처 | 게재(발표)일자
| | | | | 2020. 00. 00.
□ | 앱(APP) 등록 | 등록자명 | 앱(APP)명 | 등록처 | 등록일자
| | | | | 2020. 00. 00.
□ | 프로그램 등록 | 등록자명 | 프로그램명 | 등록처 | 등록일자
| | | | | 2020. 00. 00.
□ | 특허/실용신안 출원 | 출원자명 | 특허/실용신안명 | 출원번호 | 출원일자
| | | | | 2020. 00. 00.
□ | 기술이전 | 기술이전기업명 | 기술명 | 금액 | 이전일자
| | | | | 2020. 00. 00.
□ | 공모전 | 구분(교내/대외) | 공모전명 | 수상여부(출품/수상) | 상격
□ | 실용화 | #실용화한 내용에 대한 구체적 작품설명
□ | 기타

#입력한 달성성과에 대한 증빙자료는 별첨

Ⅲ. 프로젝트 수행방법

가. 업무분장

번호 | 성명 | 역할 | 담당업무
1 | 권 성만 | 멘 토
2 | 김 은영 | 지도교수
3 | 이 선관 | 팀 장 | - 제품 외형 모델링 및 팀내 업무 총괄
4 | 이 택기 | 팀 원4 | - 자료조사 및 문서화, 일정관리, 서기
5 | 이 재욱 | 팀 원5 | - 제품 내부 디자인 및 자료조사

나. 프로젝트 수행일정

구분 | 추진내용 | 수행일정
| | 3월 | 4월 | 5월 | 6월 | 7월 | 8월 | 9월 | 10월 | 11월
계획 | 조원 구성 및 역할분담, 일정 협의 및 일정표 작성, 제품 사전조사, 제품 사전조사, 수행계획서 작성 | ㅇ | ㅇ
분석 | 구현여부확인, 제품 필수기능 설정, 제품디자인 외형 설정, 제품의 구동방식 확인, 시제품 비교군 탐색, 수정보안점 확인 | | ㅇ | ㅇ
설계 | 3D도면 제작 및 검수 | | | ㅇ | ㅇ
| 2D도면 제작 및 검수 | | | ㅇ | ㅇ
개발 | 3D프린터를 활용한 시안 제작 | | | | ㅇ | ㅇ
| 제품 검증 및 시제품 재료 구매 | | | | | ㅇ
| 시제품 제작 | | | | | ㅇ
테스트 | 시제품 구동확인 및 오류수정 | | | | | ㅇ
종료 | 프로젝트 최종보고 및 종료 | | | | | ㅇ
오프라인 미팅 | 대면회의 및 메신저를 통한 비대면 미팅 | ㅇ | ㅇ | ㅇ | ㅇ | ㅇ

다. 문제점 및 해결방안

ㅇ 프로젝트 관리 측면

ㅇ 작품 개발 측면

Ⅳ. 기대효과 및 활용분야

ㅇ

Ⅴ. 참고자료

가. 참고 및 인용자료

ㅇ

ㅇ

[별첨] 한이음 ICT멘토링 프로젝트 산출물

DRW00000904475b

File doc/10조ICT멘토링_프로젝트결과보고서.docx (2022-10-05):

□ 서식4_한이음 ICT멘토링 프로젝트 결과보고서

2020년 한이음 ICT멘토링

프로젝트 결과보고서

프로젝트명 | IOT를 활용한 반려묘 스마트 화장실

요 약 본

프로젝트 정보
주제영역 | ■ 생활 □ 업무 □ 공공/교통 □ 금융/핀테크 □ 의료 □ 교육 □ 유통/쇼핑 □ 엔터테인먼트
기술분야 | ■ IoT □ 가상현실 | □모바일 □ 빅데이터 | □ 데스크톱 SW ■ 자동제어기술 | □인공지능 □ 블록체인 | □ 보안 □ 영상처리
달성성과 | ■ 논문게재 및 포스터발표 □ 앱등록 □ 프로그램등록 □ 특허 □ 기술이전 ■ 실용화 ■ 공모전(공모전명 ) □ 기타( )
프로젝트명 | IOT를 활용한 반려묘 스마트 화장실
프로젝트 소개 | 바쁜 현대의 반려인들에게 자동화장실은 필수라 해도 과언이 아니나 복잡한 구조와 여러 가지 부가기능으로 인해 그 가격이 매우 비싸 보급률이 낮다. 우리는 이 프로젝트를 통해 핵심기능만을 지닌, 기존 제품 대비 상대적으로 보급에 유리한 반려묘 자동화장실을 소 해보고자 한다.
개발배경 및 필요성 | 1인 가구의 증대로 반려동물에 대한 수요는 점차 증가하고 있으며 그중 실내에서 키우기 적합한 고양이에 포커스를 두고 애묘인들이 가장 힘들어하는 것이 화장실 관리라는 것을 보고 해당 제품을 기획하게 되었다.
프로젝트 주요기능 | ▶ 배변 처리 : 제품의 주요 기능으로, 모래 속에 있는 배변을 자동으로 걸러서 하부 배변 봉투로 분리해주는 기능이다. ▶ 모래 평탄화 : 배변 처리 이후 배변용 모래를 평탄화 한다. ▶ 고양이 무게 확인 : 반려묘와 변의 무게를 확인한다. ▶ IOT : 제품의 원격제어가 가능하다.
작품의 기대효과 및 활용분야 | 자동제어와 원격제어를 통해 외출 등의 이유로 보호자가 직접 제품을 관리할 수 없을 때 화장실 관리를 가능하게 한다. 핵심기능만을 적용하여 원가 절감이 가능해 자동화장실의 보급화에 유리하다.

(본문) 프로젝트 결과보고서

Ⅰ. 프로젝트 개요 이선관 홍연서 조범석 이택기 이재욱

가. 프로젝트 소개

ㅇ 반려동물 시장의 성장은 1인 가구의 증가, 소득수준 향상, 저출산, 고령화 등 다양한 사회, 환경적 요인이 복합적으로 더해져 생긴 현상이다. 국내의 반려동물 시장은 매년 15%씩 성장하고 있고 미국, 영국, 일본 등의 선진국들의 예로 볼 때 국내 반려동물 시장의 관심은 더욱 커질 것으로 보인다.


<표 1> 1인가구 증가비율 <표 2> 반려동물 시장규모 전망

ㅇ 우리나라의 경우 특히 2006년 이후 반려동물로 급증하고 있는 고양이 관련 산업이 강한 성장세로 반려동물 상업 매출 증가에 큰 영향을 미치고 있다. 2012년 기준으로 국내에서 개나 고양이를 반려동물로 기르는 비율은 17.9%로 약 359만 가구, 인구수로 환산하면 천만 명에 달하며, 동물의 수로는 556만 마리로 추산되며, 그중 고양이는 116만 마리이다. 고양이의 양육 비중은 2006년 47만 7000마리에서 2012년 116만 마리로 240% 급증했는데, 이는 사회적 요인과 고양이에 대한 의식구조의 변화에 의한 것으로 볼 수 있다. 결혼과 출산율 감소, 고령화 등의 이유로 1인 가구가 늘고 그로 인한 외로움을 반려동물을 통해 해소하려는 경향이 높아지고 있으며, 고양이에 대한 부정적인 인식 개선, 고양이의 적은 채취, 소음, 적응력과 독립적인 성향이 현재 반려인들의 라이프 스타일에 잘 적응할 수 있는 점이 고양이 사육 개체수의 증가에 큰 영향을 주고 있다.


펫테크 기기와 이용 의향

나. 개발배경 및 필요성

ㅇ 반려인들이 국내 고양이 사육 가구의 수가 급증하고 있음에도 불구하고 고양이 관련 산업 관련 제품에 대한 국내 연구는 찾아보기 힘들며, 국산 브랜드의 인지도는 현저히 낮은 상황이다. 현재 시중에 나와있는 고양이 자동화장실의 가격대는 수십만원대에서 수백만원을 호가하는 제품까지 있으며, 이는 고양이 반려인들에게 큰 부담으로 다가온다.


<표 3> 반려동물 양육 시의 애로사항


<표 4, 5> 반려동물이 혼자 있는 시간

ㅇ 반려인들이 반려동물을 키우면서 생기는 문제점 1순위가 위생과 비용적인 문제점인데, 1인 가구가 증가하는 추세인 현대에 반려동물이 홀로 있게 되는 시간이 길어지는 것은 불가피하며, 이는 고양이 화장실에 방치되어 있는 변에 의한 세균증식으로 이어진다. 이는 집 안의 악취와 고양이의 건강에 직접적으로 영향을 주는 문제이며 반려인들이 뽑는 문제점 1순위와 크게 연관된다. 그렇기 때문에 자동화장실의 필요성이 부각된다.

<표 6> 펫테크 기기와 이용 의향


<표 7> 고양이의 대변과 건강상태

다. 작품 구성도

ㅇ


- 제어장치

명칭 | 기능 | 설명
Wifi 모듈 | 네트워크를 통해 사용자의 입력, 출력을 담당 | 네트워크를 통해 사용자에게 입력을 받고 컴퓨터 모듈로 명령을 전달함 컴퓨터 모듈에서 받은 정보를 네트워크를 통해 다시 사용자에게 전달함
컴퓨터모듈 | 정보 취합 후 출력 | 해당 기기의 본체에 해당 모든 정보를 받고 취합하여 각 모듈로 전달 모든 명령과 정보 처리를 담당
무게센서 | 무게 측정으로 고양이 출입을 감지 | 고양이의 출입 감지 시 제품 작동 시작 및 종료

- 구동부

명칭 | 기능 | 설명
AC 모터 | 전원을 받고 동력을 생성함 | 전기를 통해 동력을 생성하는 역할 컴퓨터 모듈에서 받은 명령을 단순수행
기판 | 제어창에서 명령을 받고 구동부를 작동시킴 | 제어장치를 포함, 명령을 전달하는 기판 모터를 돌리게 하고 동력전달장치를 가동시킴 또한 정지를 관여함
동력전달장치 (기어) | 모터에서 발생된 운동에너지를 작동부로 전달함 | 모터에서 받은 동력을 작동부로 전달시킴

- 작동부

명칭 | 기능 | 설명
본체 | 동력을 받아 회전 | 동력전달장치로부터 동력을 전달받아 회전함으로써 내부의 배변을 걸러냄
스위치 | 사용자의 직접 입력을 받음 | 외부에 돌출된 기계식 버튼의 스위치 사용자의 입력을 직접 받아 컴퓨터 모듈로 전달
앱 연동 | 제품의 원격제어 및 가시화 | 앱 연동을 통해 핸드폰 등의 기기로 제품의 배변처리 등을 제품과 떨어져 있을 때 원격으로 제어하게 해주며, 산출된 무게와 라돈 수치 등을 가시화

- 배변통

명칭 | 기능 | 설명
무게센서 | 무게를 감지 | 고양이 및 변의 무게를 감지하여 화장실의 내부 상황 파악 및 간단한 검진 가능
탈취 장치 | 배변의 냄새 억제 | 배변의 냄새를 억제하는 필터 배변통 안쪽 장착하기 쉽게 설계
라돈 센서 | 라돈 수치측정 | 모래에서 발생하는 라돈 수치를 측정함

라. 작품의 특징 및 장점

ㅇ 많은 종류의 기존 제품에는 배변처리와 악취 문제 등 자동화장실의 필수기능에 관련된 기능 외에 수많은 부가기능들이 적용되어 있어 높은 편의성을 제공하지만 동시에 제품의 가격을 크게 올리는 문제점을 가져오는 역할 또한 겸한다. 그렇기에 우리 제품에는 배변처리 및 소결, 자동제어 등의 핵심 기능만을 적용시켜 기존 제품의 높은 가격문제를 해결할 수 있다.

Ⅱ. 프로젝트 수행결과

가. 주요기능

구분 | 기능 | 설명
S/W | IoT | 사용자에게 자동제어, 원격제어 제공. 핸드폰 등의 기기를 통해 산출된 정보 가시화
H/W | 고양이 출입 감지 | 고양이의 출입을 감지하여 제품의 작동 제어
| 배변처리 | 판이 회전하면서 모래 속에 있는 배변을 분리하고 배변통으로 배출함
| 모래 평탄화 | 판 안의 배변용 모래를 판의 회전을 통해 평탄화
| 자동제어 | 구동부 및 센서와 컴퓨터 모듈의 연결로 각 부의 자동제어 부여

나. 프로젝트 개발환경

구분 | | 항목 | 적용내역
S/W 개발환경 | OS
| 개발환경(IDE)
| 개발도구
| 개발언어
H/W 구성장비 | 디바이스
| 센서 | 무게센서
| | 라돈 센서
| 통신
| 개발언어

다. 장비(기자재/재료) 활용

번호 | 품명 | 작품에서의 주요기능
1 | 컴퓨터 모듈 (아두이노 혹은 라즈베리파이) | - 제품의 구동부 및 센서와 접목하여 자동제어기능 부여
2 | Wifi 모듈 | - 제품의 원격제어 및 산출된 정보를 가시화
3 | | -
4 | | -

라. 프로그램 작동 동영상

#URL(유튜브에 올려서 링크 – 프로그램 작동 되는 화면을 동영상으로 작성)

ㅇ https://www.youtube.com/watch?v=ReGhS7GVbm0 (기존 제품 예시)

ㅇ

마. 결과물 상세 이미지


바. 달성성과

□ | 논문게재 및 포스터발표 | 게재(발표)자명 | 논문(포스터)명 | 게재(발표)처 | 게재(발표)일자
| | | | | 2020. 00. 00.
□ | 앱(APP) 등록 | 등록자명 | 앱(APP)명 | 등록처 | 등록일자
| | | | | 2020. 00. 00.
□ | 프로그램 등록 | 등록자명 | 프로그램명 | 등록처 | 등록일자
| | | | | 2020. 00. 00.
□ | 특허/실용신안 출원 | 출원자명 | 특허/실용신안명 | 출원번호 | 출원일자
| | | | | 2020. 00. 00.
□ | 기술이전 | 기술이전기업명 | 기술명 | 금액 | 이전일자
| | | | | 2020. 00. 00.
□ | 공모전 | 구분(교내/대외) | 공모전명 | 수상여부(출품/수상) | 상격
□ | 실용화 | #실용화한 내용에 대한 구체적 작품설명
□ | 기타

#입력한 달성성과에 대한 증빙자료는 별첨

Ⅲ. 프로젝트 수행방법

가. 업무분장

번호 | 성명 | 역할 | 담당업무
1 | 권 성만 | 멘 토
2 | 김 은영 | 지도교수
3 | 이 선관 | 팀 장 | - 제품 외형 모델링 및 팀내 업무 총괄
4 | 홍 연서 | 팀 원2 | - 제품 외형 디자인 및 자료조사, 회의록 작성
5 | 조 범석 | 팀 원3 | - 제품 내부 모델링 및 자재관리
6 | 이 택기 | 팀 원4 | - 자료조사 및 문서화, 일정관리
7 | 이 재욱 | 팀 원5 | - 제품 내부 디자인 및 자료조사

나. 프로젝트 수행일정

구분 | 추진내용 | 수행일정
| | 3월 | 4월 | 5월 | 6월 | 7월 | 8월 | 9월 | 10월 | 11월
계획 | 조원 구성 및 역할분담, 일정 협의 및 일정표 작성, 제품 사전조사, 제품 사전조사, 수행계획서 작성 | ㅇ | ㅇ
분석 | 구현여부확인, 제품 필수기능 설정, 제품디자인 외형 설정, 제품의 구동방식 확인, 시제품 비교군 탐색, 수정보안점 확인 | | ㅇ | ㅇ
설계 | 3D도면 제작 및 검수 | | | ㅇ | ㅇ
| 2D도면 제작 및 검수 | | | ㅇ | ㅇ
개발 | 3D프린터를 활용한 시안 제작 | | | | ㅇ | ㅇ
| 제품 검증 및 시제품 재료 구매 | | | | | ㅇ
| 시제품 제작 | | | | | ㅇ
테스트 | 시제품 구동확인 및 오류수정 | | | | | ㅇ
종료 | 프로젝트 최종보고 및 종료 | | | | | ㅇ
오프라인 미팅 | 대면회의 및 메신저를 통한 비대면 미팅 | ㅇ | ㅇ | ㅇ | ㅇ | ㅇ

다. 문제점 및 해결방안

ㅇ 프로젝트 관리 측면

ㅇ 작품 개발 측면

Ⅳ. 기대효과 및 활용분야

ㅇ

<표 8> 반려동물 월평균 양육비용

<참고 기사-연합뉴스>

반려인들의 반려동물 양육 시 애로사항 1, 2위가 위생 관리, 지출 문제로 꼽히고 있는데 우리 제품은 언제든지 배변처리, 소결 등이 가능하기 때문에 위생 관리에 유리하다. 또한 반려묘 및 변의 무게 측정, 배변용 모래의 라돈 수치 측정을 통해 간단한 검진을 할 수 있어 반려묘의 병원비 지출도 낮출 수 있다. 이러한 점으로 가정과 요즘 많아지고 있는 펫 카페 등 다중시설에서의 구비가 손쉬워져 결과적으로 자동화장실 보급에 탄력을 줄 수 있을 것이라 생각한다.

Ⅴ. 참고자료

가. 참고 및 인용자료

ㅇ 고양이 화장실의 기능성 향상을 위한 디자인 연구(이규선, 홍익대학교 디자인콘텐츠 대학원)

ㅇ

[별첨] 한이음 ICT멘토링 프로젝트 산출물

DRW00000904475b

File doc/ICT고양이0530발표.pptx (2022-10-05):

## 고양이 없는 고양이 팀 CWCT

We don't have cats, but somehow
We are making an automated cat toilet

2022. 5. 9

## 5/16일 피드백 사항

1. 정확한 치수가 없다
2. 메뉴얼을 자세히 작성
3. 와이어 프레임 형식으로 그림 그리기
4. 모터나 아두이노가 들어갈 위치 정하기

## 5/16~5/30 진행 상황

1. 와이어 프레임/모델링

모델 치수/모터/아두이노 등 내부에 들어갈 위치 그림

2. 디자인 변경/모델링

내부 부품에 알맞게 추가 디자인, 모델링,

기존 매뉴얼 보다 자세하게 작성

3. 매뉴얼 수정

4. 부품 주문

사용할 부품 여러 개 주문으로 비교 사용 할 예정

## 와이어 프레임 /모델링


1

기존 제품의 치수를 바탕으로
정확한 치수 정하고 간단한 그림으로 표현

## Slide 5

정확한 치수(mm)


본체 치수

모래통 치수

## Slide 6

정확한 치수(cm)


배변통

## 수정디자인/ 모델링

2

제품의 외부 내부 디자인

## 수정된 외형 디자인 및 내부 구조


## 수정된 외형 디자인 및 내부 구조


## 수정된 외형 디자인 및 내부 구조


## 수정된 외형 디자인 및 내부 구조


아두이노 및 모터 내부구조 스케치
확정된 위치 아닙니다


## 추가된 디자인 - 배변통


## 모델링 간섭 체크


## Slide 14

매뉴얼 수정

기존 매뉴얼 보다 자세히 작성

3

## 매뉴얼 수정


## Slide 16

## Thanks!

Do you have any questions?

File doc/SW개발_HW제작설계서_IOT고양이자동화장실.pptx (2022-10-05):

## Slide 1

내가 기획한 ICT가
세상을 바꾼다면?


SW개발/HW제작 설계서

프로젝트 명 : IOT기술을 활용한 반려묘 스마트 화장실

2022. 8. 19.
(팀명) – 이선관, 이택기, 이재욱
Mentor 권 성 만

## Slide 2

수행 단계별 주요 산출물

단계 | 산출물 | 일반 | 응용 소프트웨어 | 응용 하드웨어
| | ∙모바일 APP ∙Web 등 | ∙빅데이터 ∙인공지능 ∙블록체인 등 | ∙IoT ∙로봇 ∙드론 등
환경 분석 | 시장/기술 환경 분석서 | △ | △ | △
| 설문조사 결과서 | △ | △ | △
| 인터뷰 결과서 | △ | △ | △
요구사항 분석 | 요구사항 정의서 | ○ | ○ | ○
| 유즈케이스 정의서 | △ | △ | △
아키텍처 설계 | 서비스 구성도(시스템 구성도) | ○ | ○ | ○
| 서비스 흐름도(데이터 흐름도) | △ | ○ | △
| UI/UX 정의서 | △ | △ | △
| 하드웨어/센서 구성도 | - | - | ○
기능 설계 | 메뉴 구성도 | ○ | ○ | ○
| 화면 설계서 | ○ | ○ | △
| 엔티티 관계도 | ○ | ○ | △
| 기능 처리도(기능 흐름도) | ○ | ○ | ○
| 알고리즘 명세서/설명서 | △ | ○ | ○
| 데이터 수집처리 정의서 | - | ○ | -
| 하드웨어 설계도 | - | - | ○
개발 / 구현 | 프로그램 목록 | ○ | ○ | ○
| 테이블 정의서 | ○ | ○ | △
| 핵심 소스코드 | ○ | ○ | ○

※ ○ 필수, △ 선택

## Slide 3

| 시장/기술 동향 분석


<표 1> 1인가구 증가비율(통계청)


<표 2> 반려동물 시장규모 전망(농수축산신문 안희경,송형근 기자)

1인 가구 및 핵가족의 급증으로 인해 국내 반려동물 시장은 매년 15%씩 증가하는 추세이며 독립적인 성향을 지녀 바쁜 현대인의 라이프 스타일과 알맞은 고양이의 사육이 증가하는 추세.

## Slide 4

| 시장/기술 동향 분석


<표 3> 반려동물 양육 시의 애로사항(KB금융그룹 2021 한국 반려동물 보고서’)

반려인들이 반려동물을 키우면서 생기는 문제점 1순위는 위생과 비용의 문제

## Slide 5

시장/기술 동향 분석


현재 시제품 대부분 핵심기능인 자동 배변처리 외의 많은 부가기능을 접목시켜 편의성을 제공하지만 그 결과로 제품의 가격이 과도하게 상승

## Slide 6

| 시장/기술 동향 분석


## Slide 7

| 요구사항 정의서

구분 | 기능 | 설명
S/W | IoT | 원격으로 제품에 대한 접근, 제어를 사용자에게 제공

구분 | 기능 | 설명
H/W | 출입 감지 | 고양이의 출입을 감지하여 제품의 작동 제어
| 배변처리 | 판이 회전하면서 모래 속에 있는 배변을 분리하고 배변통으로 배출함
| 모래 평탄화 | 판 안의 배변용 모래를 판의 회전을 통해 평탄화
| 탈취 | 고양이의 배변활동에서 발생하는 악취 제거
| 라돈 측정 | 배변용 모래에서 검출되는 라돈 수치 측정
| 무게 측정 | 고양이와 변의 무게 변화 측정

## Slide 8

| 시스템 구성도


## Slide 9

| 시스템 구성도


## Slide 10

| 시스템 구성도


명칭 | 기능 | 설명
Wifi 모듈 | 네트워크를 통해 사용자의 입력, 출력을 담당 | 네트워크를 통해 사용자에게 입력을 받고 컴퓨터 모듈로 명령을 전달함 컴퓨터 모듈에서 받은 정보를 네트워크를 통해 다시 사용자에게 전달함
컴퓨터 모듈 | 정보 취합 후 출력 | 해당 기기의 본체에 해당 모든 정보를 받고 취합하여 각 모듈로 전달 모든 명령과 정보 처리를 담당
무게센서 | 무게 측정으로 고양이의 출입 감지 | 고양이의 출입 감지 시 제품 작동 시작 및 종료


명칭 | 기능 | 설명
스텝 모터 | 전원을 받고 동력을 생성함 | 전기를 통해 동력을 생성하는 역할 컴퓨터 모듈에서 받은 명령을 단순수행
기판 | 제어창에서 명령을 받고 구동부를 작동시킴 | 제어장치를 포함, 명령을 전달하는 기판 모터를 돌리게 하고 동력전달장치를 가동시킴 또한 정지를 관여함
동력전달장치 | 모터에서 발생된 운동에너지를 작동부로 전달함 | 모터에서 받은 동력을 작동부로 전달시킴

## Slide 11

| 시스템 구성도

명칭 | 기능 | 설명
본체 | 동력을 받아 회전 | 동력 전달 장치로부터 동력을 전달받아 회전함으로써 내부의 배변을 걸러냄
스위치 | 사용자의 직접 입력을 받음 | 외부에 돌출된 기계식 버튼의 스위치 사용자의 입력을 직접 받아 컴퓨터 모듈로 전달
앱 연동 | 라돈 수치측정 | 앱 연동을 통해 핸드폰 등의 기기로 제품의 배변처리 등을 제품과 떨어져 있을 때 원격으로 제어하게 해주며, 산출된 무게와 라돈 수치 등을 가시화


명칭 | 기능 | 설명
무게센서 | 무게를 측정 | 고양이 및 변의 무게를 감지하여 화장실의 내부 상황 파악 및 간단한 검진 가능
탈취 필터 | 배변의 냄새 억제 | 배변의 냄새를 억제하는 필터 배변통 안쪽 장착하기 쉽게 설계
라돈 센서 | 라돈 수치측정 | 모래에서 발생하는 라돈 수치를 측정함

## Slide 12

| 하드웨어/센서 구성도


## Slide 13

| 서비스 구성도


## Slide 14

| 기능 처리도(기능 흐름도)

프로그램 ID | toilet monitor_CWCT | 프로그램 명 | 자동 배변처리기 모니터링 프로그램 | 작성일 | 2022. 7. 12. | Page | 1/1
개요 | 자동 배변처리기의 고양이 및 변의 무게 측정값과 라돈 수치 측정값의 실시간 모니터링을 제공해주는 프로그램 | | | | | 작성자 | 이재욱

기능 흐름도

1에서 선택한 사항을 핸드폰으로 실시간 모니터링 기능 및 알림을 송신한다.

IoT 실행

측정 옵션 선택
(고양이 무게,
변 무게, 라돈 수치)

측정값 DB 저장

1

N

측정값 송신

2

고양이 무게 측정

변 무게 측정

1

2

APP 실행하여 측정 옵션을 선택한다.

라돈 수치 측정

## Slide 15

| 하드웨어 설계도


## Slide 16

| 프로그램 목록


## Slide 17

| 참조-개발 환경 및 설명

구분 | | 항목 | 적용내역
S/W 개발환경 | | Wifi 모듈(미정) | 네트워크를 통해 사용자에게 입력을 받고 컴퓨터 모듈로 명령을 전달함 컴퓨터 모듈에서 받은 정보를 네트워크를 통해 다시 사용자에게 전달함
H/W 구성장비 | 디바이스 | 컴퓨터 모듈(미정) | 제품의 구동부, 센서와 결합하여 고양이의 출입을 통한 제품의 작동 자동제어
| | 아두이노 호환 5V 스텝모터 [SZH-EK060] | 모터의 동력을 통한 제품의 다양한 각도의 회전운동을 통해 배변처리 및 모래 평탄화 진행
| 센서 | 저가형 3선식 로드셀(50Kg) | 변의 잔류를 무게 측정을 통해 확인할 수 있으며 그 신호에 의해 반복 작동 필요 판단
| | 아두이노 호환 감마센서 모듈(GDK101) | 배변용 모래의 라돈 수치를 측정하여 모래의 교체 필요성 확인 및 사고 예방

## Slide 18

| 핵심 소스코드

#define motorPin1 2 // IN1

#define motorPin2 3 // IN2

#define motorPin3 4 // IN3

#define motorPin4 5 // IN4

#define step 2048 // 1봐퀴 스텝수

// 모터 회전 Loop 문 구현을 간단하게 하기위해 핀 배열 선언
int pinArray[4] = { motorPin1, motorPin2, motorPin3, motorPin4 };
// CW 시계방향 데이터 전송
int CW[4] = {
0b1000,
0b0100,
0b0010,
0b0001
};
int CCW[4] = {
0b0001,
0b0010,
0b0100,
0b1000
};
void setup(){
// 핀모드 설정
// 스텝모터 드라이브 보드의 IN 연결핀 출력으로 설정
for(int i = 0 ; i < 4 ; i++ ) {
pinMode(pinArray[i], OUTPUT);
}
}

void loop() {
int temp;
// CW방향 1바퀴 후
for(int i = 0 ; i < step ; i++)
{
temp = i % 4;
digitalWrite(pinArray[0], bitRead(CW[temp], 0));
digitalWrite(pinArray[1], bitRead(CW[temp], 1));
digitalWrite(pinArray[2], bitRead(CW[temp], 2));
digitalWrite(pinArray[3], bitRead(CW[temp], 3));
stepDelay();
}
delay(500);
// CCW 1바퀴
for(int i = 0 ; i < step ; i++)
{
temp = i % 4;
digitalWrite(pinArray[0], bitRead(CCW[temp], 0));
digitalWrite(pinArray[1], bitRead(CCW[temp], 1));
digitalWrite(pinArray[2], bitRead(CCW[temp], 2));
digitalWrite(pinArray[3], bitRead(CCW[temp], 3));
stepDelay();
}
delay(500);
}
void stepDelay()
{
// 모터 부하가 없는 상태에서,
// 각 스텝 간격이 최소 3ms 이상이어야 정상적으로 동작합니다.
delay(3);
}

모터 구동 코드

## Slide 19

내가 기획한 ICT가
세상을 바꾼다면?

Thank you


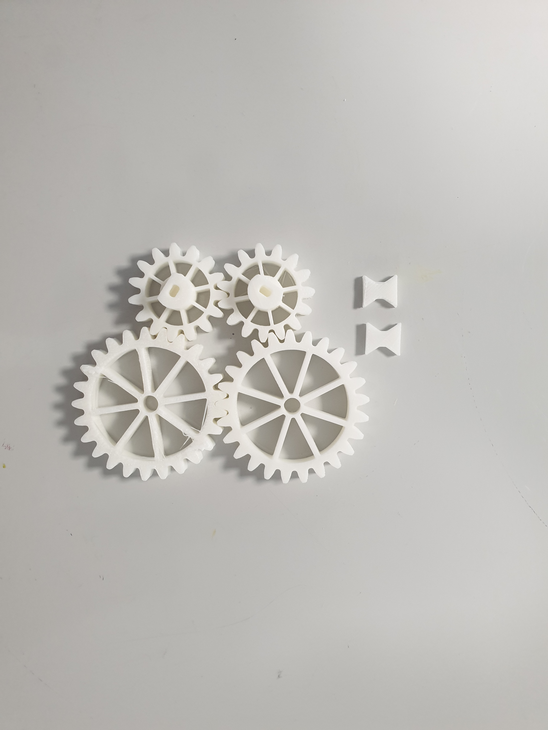
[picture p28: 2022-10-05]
images/KakaoTalk_20221005_131710617_09.jpg

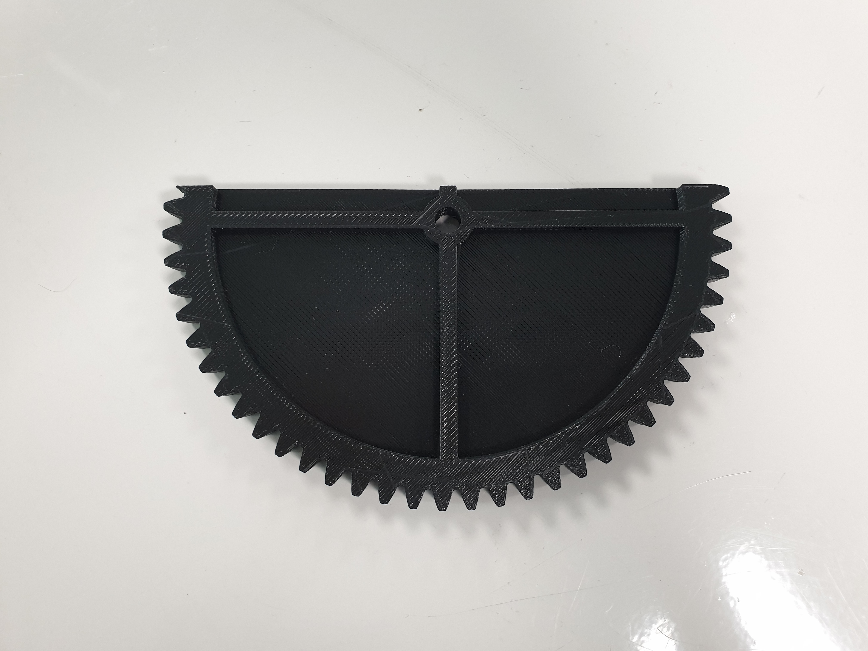
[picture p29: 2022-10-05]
images/KakaoTalk_20220705_162518360_04.jpg

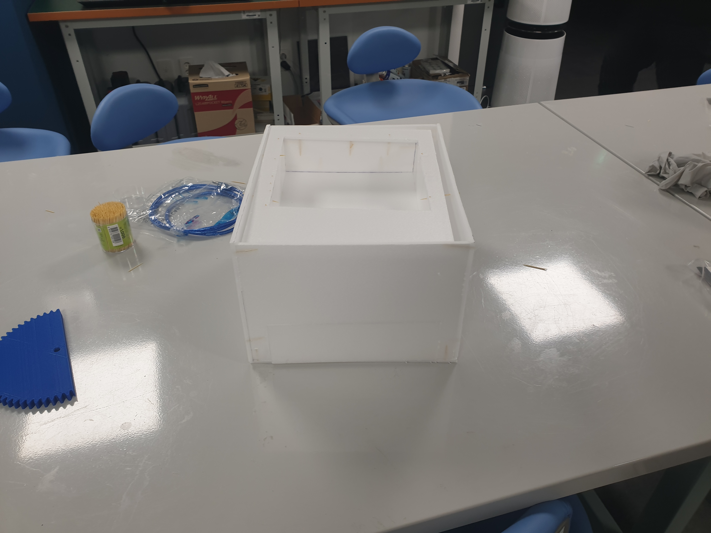
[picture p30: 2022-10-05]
images/KakaoTalk_20220705_105104796_02.jpg

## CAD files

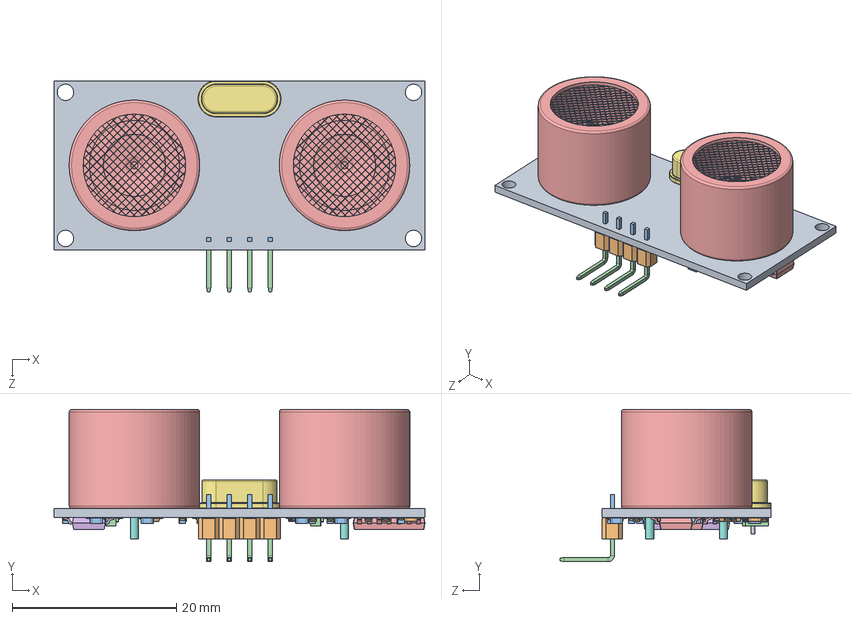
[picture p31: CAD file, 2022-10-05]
modeling/컴포넌트/ㅇ/Ultrasonic Sensor HC-SR04/Ultrasonic Sensor HC-SR04.SLDASM
45.2 x 18.5 x 25.8 mm
hc-sr04 part1
hc-sr04 part2
hc-sr04 part3 x 4
hc-sr04 part4 x 4
hc-sr04 part5 x 2
hc-sr04 part6 x 2
hc-sr04 part7
hc-sr04 part8 x 4
hc-sr04 part13 x 2
SMD resistor x 21
SMD resistor2 x 15
hc-sr04 part9 x 2
hc-sr04 part10 x 2
hc-sr04 part11
hc-sr04 part12 x 78

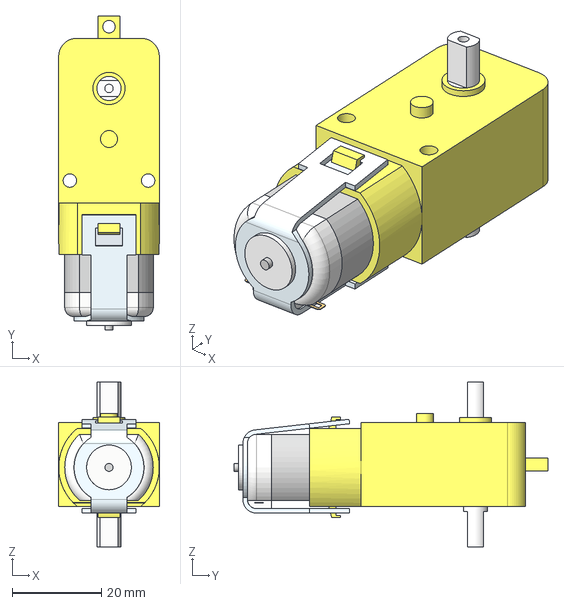
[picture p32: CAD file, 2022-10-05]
modeling/컴포넌트/TT Motor.step
22.5 x 70.2 x 36.8 mm

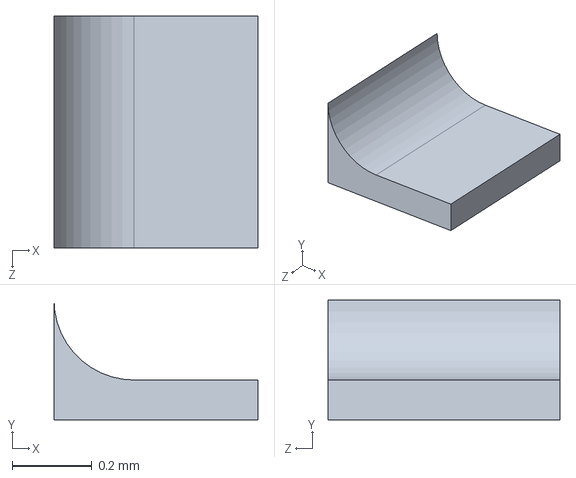
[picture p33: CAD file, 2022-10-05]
modeling/컴포넌트/ㅇ/Ultrasonic Sensor HC-SR04/hc-sr04 part12.SLDPRT
0.51 x 0.3 x 0.58 mm

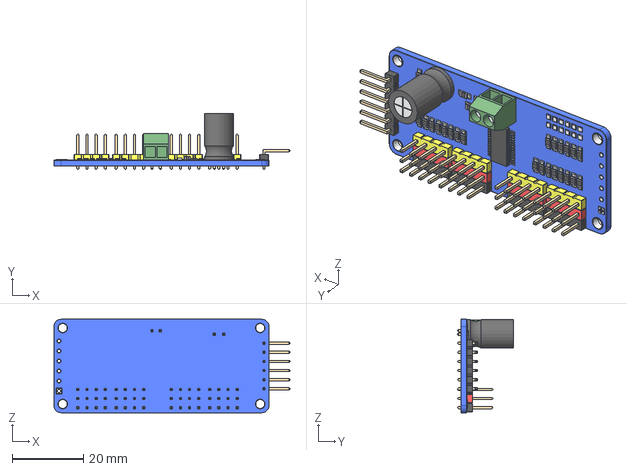
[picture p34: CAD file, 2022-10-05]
modeling/컴포넌트/두견/PCA9685 v18.step
66.1 x 15.6 x 26.2 mm

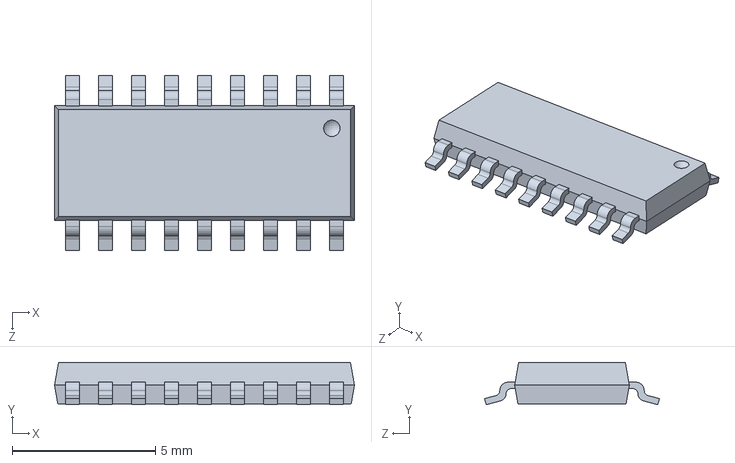
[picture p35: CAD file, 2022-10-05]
modeling/컴포넌트/ㅇ/Ultrasonic Sensor HC-SR04/hc-sr04 part11.SLDPRT
10.5 x 1.48 x 6.10 mm

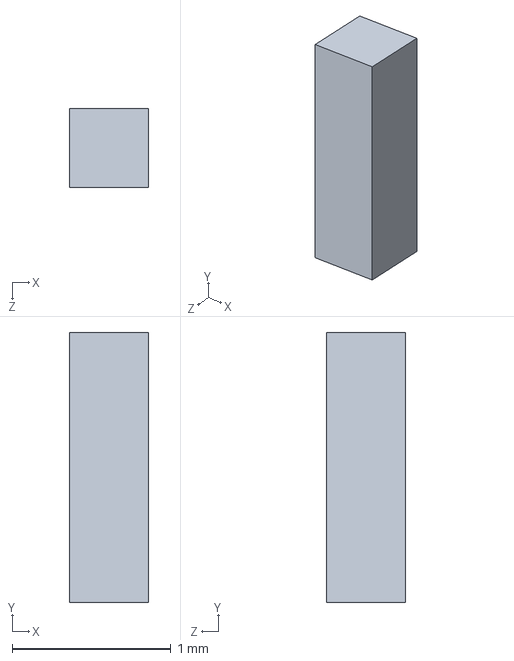
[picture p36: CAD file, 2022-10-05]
modeling/컴포넌트/ㅇ/Ultrasonic Sensor HC-SR04/hc-sr04 part3.SLDPRT
0.5 x 1.70 x 0.5 mm

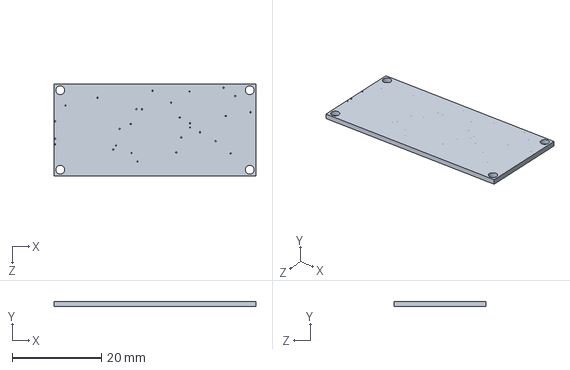
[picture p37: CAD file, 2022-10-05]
modeling/컴포넌트/ㅇ/Ultrasonic Sensor HC-SR04/hc-sr04 part1.SLDPRT
45.2 x 1.10 x 20.6 mm

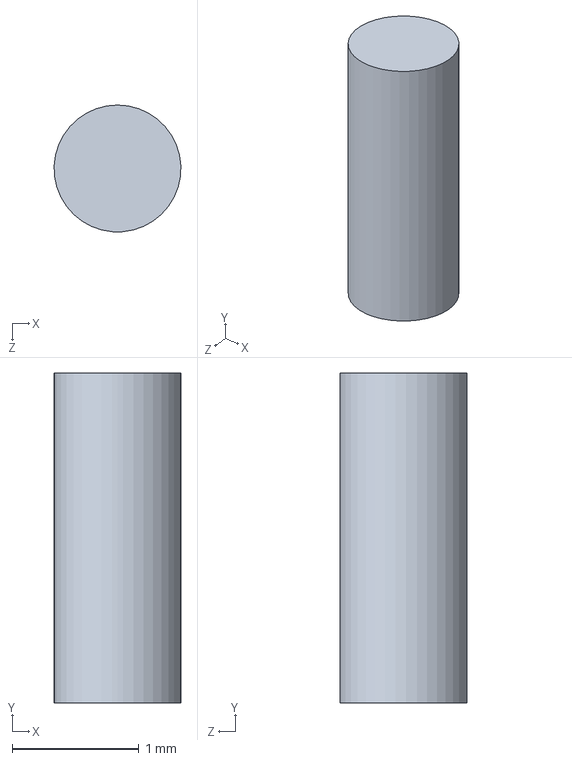
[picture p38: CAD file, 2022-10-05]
modeling/컴포넌트/ㅇ/Ultrasonic Sensor HC-SR04/hc-sr04 part8.SLDPRT
0.999 x 2.60 x 1.00 mm

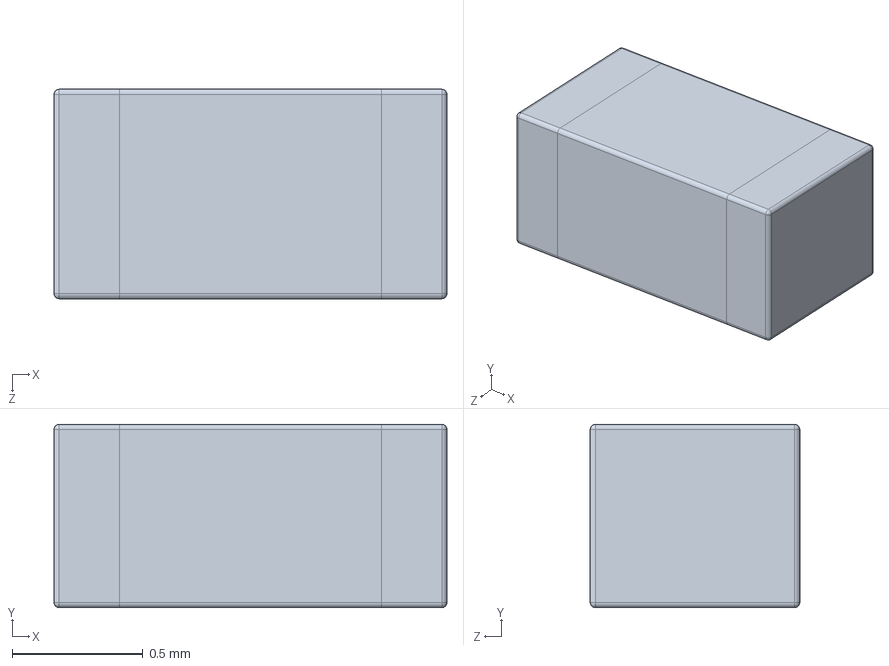
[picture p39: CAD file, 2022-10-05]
modeling/컴포넌트/ㅇ/Ultrasonic Sensor HC-SR04/SMD resistor2.SLDPRT
1.50 x 0.7 x 0.8 mm

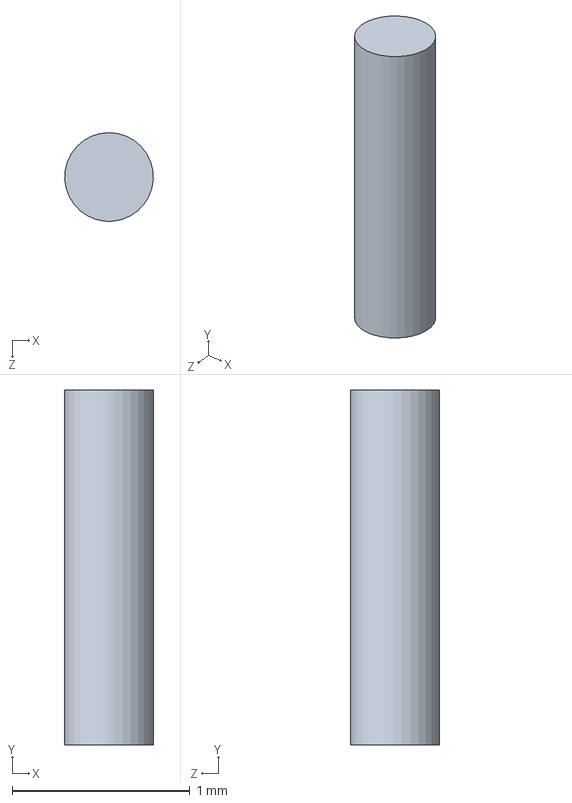
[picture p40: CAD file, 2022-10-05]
modeling/컴포넌트/ㅇ/Ultrasonic Sensor HC-SR04/hc-sr04 part13.SLDPRT
0.499 x 2.00 x 0.5 mm

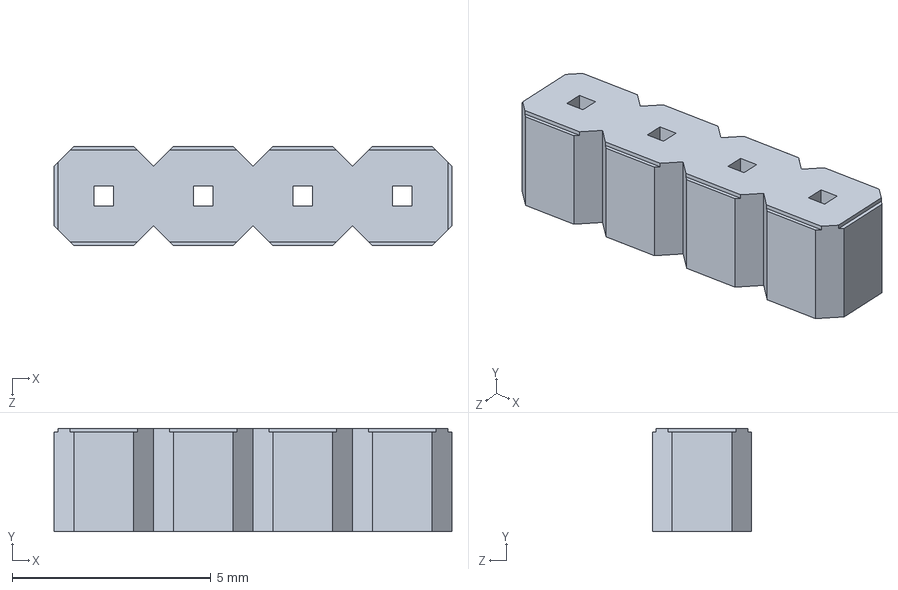
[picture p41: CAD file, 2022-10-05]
modeling/컴포넌트/ㅇ/Ultrasonic Sensor HC-SR04/hc-sr04 part2.SLDPRT
10.0 x 2.60 x 2.50 mm

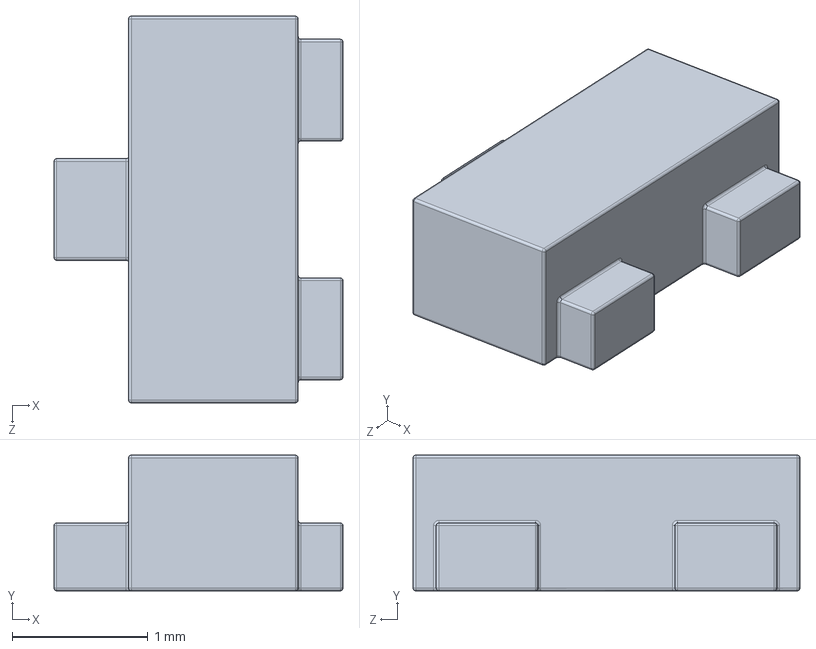
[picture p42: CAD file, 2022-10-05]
modeling/컴포넌트/ㅇ/Ultrasonic Sensor HC-SR04/hc-sr04 part9.SLDPRT
2.13 x 1.00 x 2.85 mm

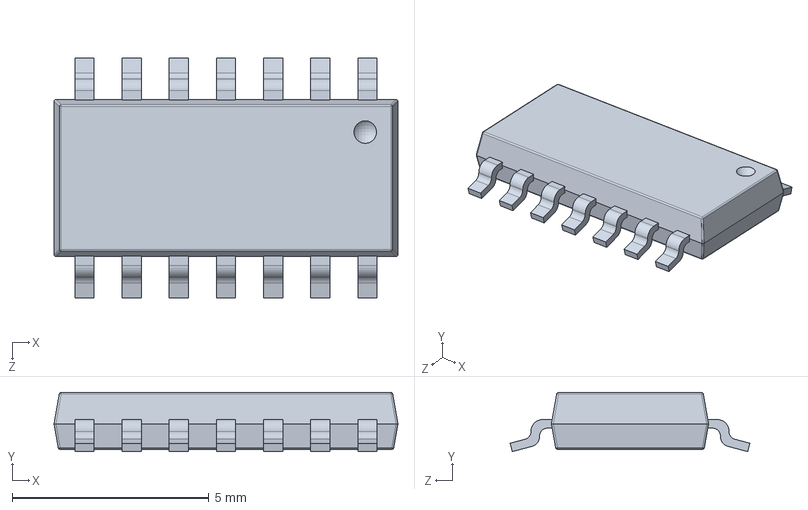
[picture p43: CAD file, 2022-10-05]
modeling/컴포넌트/ㅇ/Ultrasonic Sensor HC-SR04/hc-sr04 part10.SLDPRT
8.75 x 1.51 x 6.10 mm

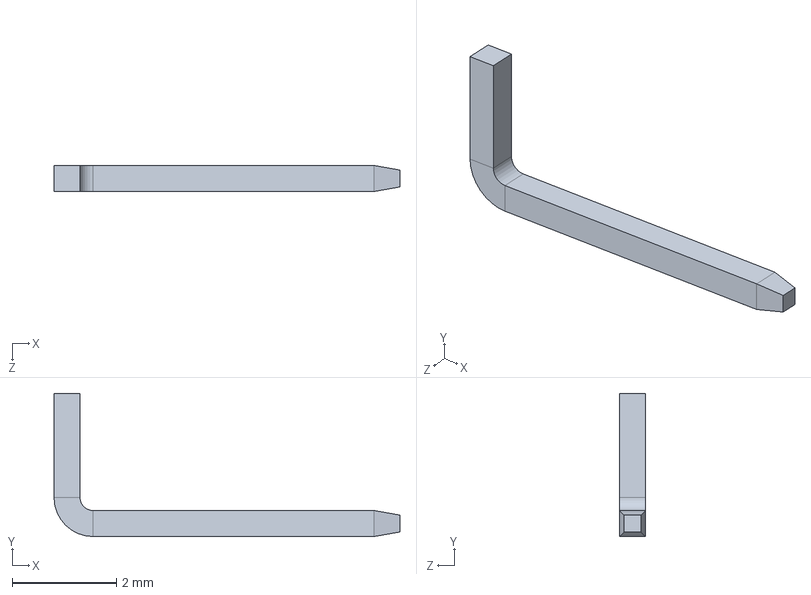
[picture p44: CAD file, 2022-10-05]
modeling/컴포넌트/ㅇ/Ultrasonic Sensor HC-SR04/hc-sr04 part4.SLDPRT
6.65 x 2.75 x 0.5 mm

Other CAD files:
modeling/컴포넌트/ㅇ/Ultrasonic Sensor HC-SR04/hc-sr04 part5.SLDPRT
modeling/컴포넌트/ㅇ/Ultrasonic Sensor HC-SR04/SMD resistor.SLDPRT
modeling/컴포넌트/ㅇ/Ultrasonic Sensor HC-SR04/hc-sr04 part7.SLDPRT
modeling/컴포넌트/ㅇ/Ultrasonic Sensor HC-SR04/hc-sr04 part6.SLDPRT
modeling/CWCT 최종 모델링/02_모래통 스플릿_v2.prt
modeling/CWCT 최종 모델링/03_배변통.prt
modeling/CWCT 최종 모델링/04_거름망 수정.prt
modeling/CWCT 최종 모델링/M3나사.prt
modeling/CWCT 최종 모델링/M4나사.prt
modeling/CWCT 최종 모델링/dc모터.prt
modeling/CWCT 최종 모델링/경첩.prt
modeling/CWCT 최종 모델링/기어박스.prt
modeling/CWCT 최종 모델링/모터 드라이버.prt
modeling/CWCT 최종 모델링/모터 브라켓+모터(좌) 모자.prt
modeling/CWCT 최종 모델링/모터 브라켓+모터(좌).prt
modeling/CWCT 최종 모델링/모터 브라켓+모터.prt
modeling/CWCT 최종 모델링/브라켓 수정1차.prt
modeling/CWCT 최종 모델링/브라켓 수정2차.prt
modeling/CWCT 최종 모델링/브라켓 수정3차.prt
modeling/CWCT 최종 모델링/브라켓.prt
modeling/CWCT 최종 모델링/샤프트(와셔x).prt
modeling/CWCT 최종 모델링/샤프트.prt
modeling/CWCT 최종 모델링/아래기어.prt
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

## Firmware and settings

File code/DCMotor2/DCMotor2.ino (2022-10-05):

#include <SoftwareSerial.h>
#define BT_RXD 8
#define BT_TXD 9

SoftwareSerial bluetooth(BT_RXD, BT_TXD);

// 3번과 4번 핀은 모터 제어에 관한 핀
int IN1Pin = 3;
int IN2Pin = 4;
int sensorpin1 = 6;
int sensorpin2 = 7;
int val1 = 0; // 포토센서핀 값을 받는다 기본 0
int val2 = 0; // 2번포토센서값
int buttonpin = 12;

// 5번핀은 모터의 힘을 설정해주는 핀
int ENAPin = 5;
int buzzerPin = 13;

unsigned long time_previous, time_previous1, time_current = 0;
const long delayTime = 1000;
boolean buzzerState = false;

void setup() {
  Serial.begin(9600);
  bluetooth.begin(9600);

  Serial.println("START");
  pinMode(IN1Pin, OUTPUT);
  pinMode(IN2Pin, OUTPUT); // 3, 4번 제어핀들은 핀모드를 출력은로 설정
  analogWrite(ENAPin, 255); //5번 핀에 255의 최대 힘을 설정한다. 
  pinMode(buzzerPin, OUTPUT);
  pinMode(buttonpin, INPUT);

  int button = 0;
}



void loop() {

   char val = bluetooth.read();
   val2 = digitalRead(sensorpin2);
   
  if(bluetooth.available()){
    Serial.write(bluetooth.read());
  }



  while(val == 'a') {
    val1 = digitalRead(sensorpin1);
      Serial.println(val1);
    if(val1 == LOW){
      digitalWrite(IN1Pin, HIGH); 
      digitalWrite(IN2Pin, LOW);
      }
     else{
      digitalWrite(IN1Pin, LOW);
      digitalWrite(IN2Pin, LOW);
      Serial.print("STOP");
      tone(buzzerPin, 131);
      delay(500);
      noTone(buzzerPin);
      break;
     }
    }
  
  while(val == 'b') {
    val2 = digitalRead(sensorpin2);
      Serial.println(val2);
    if(val2 == LOW){
      digitalWrite(IN1Pin, LOW); 
      digitalWrite(IN2Pin, HIGH);
      }
     else{
      digitalWrite(IN1Pin, LOW);
      digitalWrite(IN2Pin, LOW);
      Serial.print("STOP");
      tone(buzzerPin, 131);
      delay(500);
      noTone(buzzerPin);
      break;
     }
    }

  if(val == 'c') {
  //Brake (Stop) 핀 3, 4에 똑같이 High를 주거나 Low을 주면 은 멈춘다.
   digitalWrite(IN1Pin, HIGH);
   digitalWrite(IN2Pin, HIGH);
  }
 }

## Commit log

2022-08-10 일정관리
2022-08-10 구글문서
2022-10-05 doc and research
    [일정표초안.xlsx]
2022-10-05 modeling and product
    [02_모래통 스플릿_v2.prt, 03_배변통.prt, 04_거름망 수정.prt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]
